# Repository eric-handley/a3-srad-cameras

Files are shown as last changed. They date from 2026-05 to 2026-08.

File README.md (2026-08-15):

# SRAD Cameras -  Operator's Manual

Please read the following document carefully as there are several important notes that could result in data loss or damage if ignored. After the rocket is recovered, please follow [Post-Flight Operations](#post-flight-operations).

Various tools for interacting with the camera boards have been provided in `./tools`. Each of these scripts can be passed `-h` as a flag to see the correct usage. Usage of these scripts is also detailed throughout this file. These scripts + this manual is largely written with the assumption that the user is on a reasonably mainstream Linux distro with common tools available. 

You will need a USB-C cable to pull files off of the camera (although the SD card should be imaged after flight as a precaution before doing this) and a USB<->UART adapter to send/receive camera commands/status.

Please send me a message if uncertain about anything or if issues arise!

## Table of Contents

- [Pre-Flight Checklist](#pre-flight-checklist)
    - [FPC Cable](#fpc-cable)
    - [Arducam Module](#arducam-module)
    - [SD Card](#sd-card)
    - [Operational Test](#operational-test)
    - [Before Launch](#before-launch)
- [Important Warnings & Info](#important-warnings--info)
- [Board Info](#board-info)
    - [Camera Status](#camera-status)
    - [Correct FPC Orientation](#correct-fpc-orientation)
    - [Arducam Ribbon connector](#arducam-ribbon-connector)
- [SD Card Operations](#sd-card-operations)
    - [SD Card Format](#sd-card-format)
- [Recovering Recordings](#recovering-recordings)
    - [Post-Flight Operations](#post-flight-operations)
    - [Pulling Recordings Directly](#pulling-recordings-directly)
- [Inspecting Recording Logs for Issues](#inspecting-recording-logs-for-issues)
    - [Common Errors & Causes](#common-errors--causes)
    - [`CAM2` Errata](#cam2-errata)

## Pre-Flight Checklist

This checklist is per-camera, e.g. each item should be checked on each camera module.

##### FPC Cable

- [ ] FPC is securely connected to both boards, without unneccesary strain, bends, or creases
- [ ] The FPC cable is oriented correctly (see [Correct FPC Orientation](#correct-fpc-orientation))
- [ ] The FPC cable is routed safely, away from power cables and PCBs (see [Important Warnings & Info](#important-warnings--info))
- [ ] If time permits, 3D print a cover for `CAM1` (Recovery Bay camera) to hold FPC away from board. Leave gap for airflow over SoC

##### Arducam Module

- [ ] The small black ribbon connector on the back of the module is in place (see [Arducam Ribbon connector](#arducam-ribbon-connector))
- [ ] The lens is oriented properly and lines up with its viewport (into Recovery/out of fuselage)

##### SD Card

- [ ] The SD card has been cleared using [./tools/wipe-sd-data](./tools/wipe-sd-data) (see [SD Card Operations](#sd-card-operations)) OR it has been verified over SSH using the `df` utility that the `/data` partition retains a significant portion of its capacity (preferably >50%)

##### Operational Test

- [ ] The camera board responds to `START`/`STOP` commands and correctly enters into and reports `STARTING`/`RECORDING`/`STOPPING`/`STOPPED` states based on commands from the Flight Computer/Ground Station
- [ ] After the above, the recording/logs can be pulled from the card properly using [./tools/pull-recording](./tools/pull-recording) (see [Recovering Recordings](#recovering-recordings))
- [ ] No non-benign error messages are reported in the various recording log files (see [Inspecting Recording Logs for Issues](#inspecting-recording-logs-for-issues))
- [ ] The resulting files can be properly combined using [./tools/mux](./tools/mux) and play without issues

##### Before Launch

- [ ] Power and UART lines are securely connected to the camera board and to Modular Power Supply/Flight Computer
- [ ] **IMPORTANT**: Slide switch on the camera board is in the `ON` position (closest to USB-C port)

## Important Warnings & Info

> [!WARNING]
> The SD cards already in the cameras have been correctly formatted as the SoC expects. You CANNOT clear or zero the entire SD card as this will wipe the OS!

> [!NOTE]
> The SD cards do not have a standard partition table as the SoC does not support this. This means that if you plug the SD card into your computer you will not see individual partitions/sizes/filesystem types, and it is not possible to pull files off the SD card this way. This is to be expected and is not an error. 

> [!WARNING]
> Do NOT plug in the USB-C cable while the main camera board is either powered through `JST1` or connected to the Modular Power Supply! Neither device has reverse-voltage protection for this scenario and the outcome of this is unpredictable and potentially damaging.

> [!WARNING]
> ALWAYS ensure that the camera reports a `STOPPED`/`0x0` state before switching it off or disconnecting it from the power supply. Sending `STOP` allows the camera to safely power down the SoC and unmount the SD card. While significant consideration has been given to preventing data loss during power-cut events, we do not want this to happen any more than necessary! The only time power should potentially be cut directly is during a non-nominal flight.

> [!NOTE]
> It is not possible to send commands that cause the camera to shut off in an unsafe way (unless the camera decides that this is necessary, e.g. in the case of SoC responses timing out). Sending `START` or `STOP` commands in any state will always be handled in a way that allows the SoC to unmount the SD card and shut down safely.

> [!CAUTION]
> Ensure the 1x22 FPC cable between the main camera board and the Arducam module is routed as far as possible from power cables and PCBs. The FPC should NEVER be pressed up against either the main camera PCB or the back of the Arducam PCB as this may cause the data sent through it to be corrupted. If this happens during flight, the recording will continue safely, but some non-zero number of frames will likely be lost.

## Board Info

### Camera Status

The status LED between the two JST connectors will blink 3 times on power-up to indicate that the STM32 has started. After this has completed, the LED has three possible states that indicate the overall status of the camera:

1. `STANDBY`: 5 seconds off, then 1 short blink
2. `RECORDING`: ~800 ms off, then ~800 ms on
    - Also present while the camera is `STOPPING`
    - The camera will stop `RECORDING` automatically after 30 minutes and shut down
3. `ERROR`: Rapidly blinking on/off every ~100 ms
    - This state may be temporary as the camera will try to recover automatically
    - If `ERROR` persists for more than a couple seconds, the best course of action is to send `STOP`, wait for `STOPPED`, then start the camera in `IDLE` and inspect the logs for the source of the issue
    - If no logs are produced by an `ERROR` state then the SoC never booted - this is caused by the PMIC on the PCB failing to start and the issue is likely related to voltage instability or unstable/poor ground connection. This is also a good first thing to check if errors occur

While the camera is in a transitional state between `STOPPED`/`STANDBY` and `RECORDING`, it will report either `STARTING` or `STOPPING`. This indicates that the SoC is in the process of booting or shutting down safely.

### Correct FPC Orientation

The correct orientation for the FPC ribbon cable is shown below. The cameras (as shipped) already have this orientation and ideally there is no need to disconnect the cable. However, this image can be referenced if necessary. The easiest way to tell that the cable orientation is correct is that the **blue rectangle on each end of the cable** should face: (a) toward the same side as the camera lens and (b) toward the top of the main board

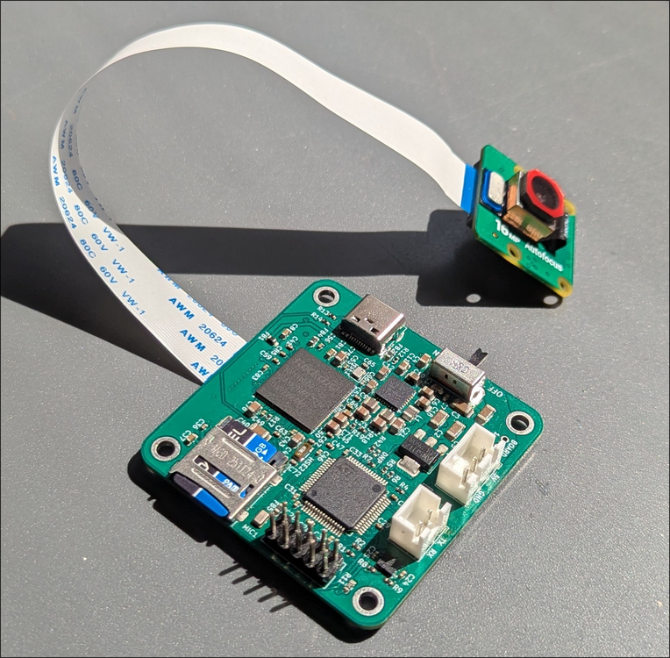
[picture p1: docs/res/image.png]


To disconnect either side of the cable, you must first pull the two black tabs beside the cable out (shown in the image below). If you are pulling on the cable with any amount of force and it is not coming out, you have skipped this step! To put the cable back:

 - Make sure the black tabs are out
 - Insert the cable in the right orientation
 - GENTLY push the black tabs back into place, ideally while holding the other side of the connector 

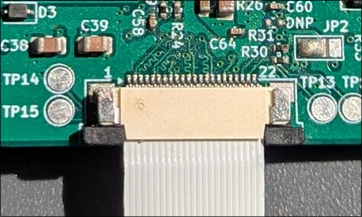
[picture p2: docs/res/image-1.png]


### Arducam Ribbon connector

The back of the Arducam B0371 module has a small ribbon connector that carries various signals/voltages. This cable can easily become disconnected if the module is not handled carefully. Simply align the contacts and push the cable back into place.

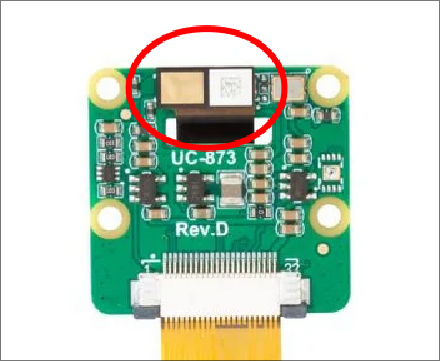
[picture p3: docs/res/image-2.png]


## SD Card Operations

As noted in [Important Warnings & Info](#important-warnings--info), the MicroSD card used by the SoC has a non-standard partition setup to allow the SoC to properly read it. This means that you cannot a) mount the SD card as a regular drive with visible partitions or b) easily pull recordings off of the card by plugging it into your computer. Instead, follow [Recovering Recordings](#recovering-recordings).

### SD Card Format

The majority of the pre-written data on the MicroSD cards is the operating system used by the SoC; this should not be modified or overwritten under any circumstances. All recording data/logs are saved in the `/data` folder, which is a separate partition. All other partitions are always mounted read-only by the OS to avoid corruption. To safely clear the `/data` partition to clear up room for more recordings, you should do the following:

1. Save any recordings you want to keep (see [Pulling Recordings Directly](#pulling-recordings-directly))
2. Plug the SD card into your computer. Ensure it remains unmounted
3. Get the name of the device using `lsblk` (usually `mmcblk0`)
4. Use [./tools/wipe-sd-data](./tools/wipe-sd-data): `./wipe-sd-data <device-name>` to clear the data partition and safely reinitialize the ext4 filesystem it uses. The script will prompt you to confirm that the name of the device is correct before running

It is also possible to free up space by using [./tools/ssh-cam](./tools/ssh-cam) to SSH into a camera board over USB-C, then running `rm -rf /data/*`. However, this has the disadvantage of not fully reinitializing the filesystem used by the `/data` partition (thus potentially leaving corrupted filesystem info behind).

## Recovering Recordings

### Post-Flight Operations

Following recovery of the rocket, the following steps should be taken.

>[!WARNING]
> Do not mount the MicroSD cards and ensure that the computer used for this task will NOT attempt to automatically mount them! Some distros may be configured to do this when new disks are detected. It's unlikely this would cause issues but the risk should not be taken.

1. Switch off each camera and disconnect from Modular Power Supply
2. Remove SD cards from camera boards. Use the [./tools/image-sd](./tools/image-sd) utility to image both SD cards and save the raw contents to a file. Ideally label these `cam1.img` and `cam2.img` accordingly.
    - This is a backup precaution to make sure that (in the event of corruption) we have an exact copy of the disk before the OS attempts to repair it
    - Note: This will take quite a while and requires that your computer have at least 64GiB free
3. Once each camera's SD card has a `.img` file, you can attempt to pull the recordings using the boards directly (see next subsection). This is a significantly easier process than trying to extract them from the `.img` file manually.

### Pulling Recordings Directly

To put the cameras in a state where you can SSH into them or SCP files off of them, you must do the following:

1. Disconnect any other power sources from the board
2. **If post-flight**: Image the SD card as specified in the previous subsection
3. Plug the board into your computer using a USB-C cable
4. Connect a USB<->UART adapter to ground and to the `JST2`/1x2 Flight Computer connector OR the two header pins labled `FC` `RX/TX` on the back of the board.
5. Use [./tools/cam-send](./tools/cam-send) to send an `IDLE` command to the board: `./cam-send idle`. This boots the SoC without starting a recording. 
    - Note that in this mode, the `/data` partition is mounted read-only and therefore direct power cuts are not a concern (but getting in the habit of sending `./cam-send stop` before you disconnect the USB-C is still a good idea)
6. Use [./tools/pull-recording](./tools/pull-recording) to pull a single recording off of the SD card: `./pull-recording latest`
    - If you have not yet registered the camera's USB interface as an ethernet device, the script will prompt you to run `./tools/ssh-cam`, which should handle this automatically
    - `/data/latest` is a symlink to the most recently completed recording
    - Make sure if you are pulling `latest` multiple times that you rename the folder before pulling `latest` again - otherwise the contents will be overwritten.
7. Use [./tools/mux](./tools/mux) to combine the audio/video streams into a single `.mp4` file: `./mux <recording folder name>`
    - Requires `ffmpeg` and `mkvmerge` to be installed
    - Pretty please if you send this somewhere, do it in a way that doesn't destroy the bitrate/compress the video in a way that kills visual quality 🥲

Pulling any recording will also give you a `recordings.log` file. This file lists the folder names of all recordings made, e.g:

```
4aa29dfe5f15 <- saved in /data/4aa29dfe5f15
3362371f0132
7be752e098c8
75d7f5291437
7910d149b82b
becfb81627f5 <- most recent recording folder, /data/latest points here
```

## Inspecting Recording Logs for Issues

The following files should be created/updated by each recording (`START`/`STOP` cycle). If some are missing or duplicated (e.g. the same filename with a `.1`, `.2` suffix - this indicates a supervisor retry), something has gone wrong.

```sh
data
├── latest              # or uuid12 e.g. e051225d1440. `latest` is a symlink for most recent recording
│   ├── audio.log       # logs for `tinycap` which captures audio from ALSA
│   ├── audio.wav       # actual audio output file
│   ├── imu.csv         # timestamped imu data from STM32 along with temperature sensor readings
│   ├── kernel.log      # kernel logs for specific boot that captured this recording
│   ├── supervisor.log  # logs for supervisor script that starts other processes, e.g. video and 
│   │                   # audio recording. also handles logging imu data from STM32
│   ├── vicap.log       # logs from video capture process
│   ├── video.h265      # output h265 video
│   └── video.pts       # timestamps of every frame of h265. allows muxing to time frames 
│                       # correctly instead of distributing evenly according to FPS
├── recordings.log      # records the folder names of each new recording created
└── startup.log         # records an entry each time the supervisor script starts
```

#### Common Errors & Causes

> [!NOTE]
> Expect to see a fair amount of errors like the following:
> ```
>3,309,22874610,-;dwmmc_rockchip ffaa0000.mmc: Card stuck in wrong state! card_busy_detect status: 0x0 caller=mmc_blk_mq_complete_prev_req.part.4+0x89/0xe4
>3,310,22874669,-;MMCDBG mmcblk1: recovery dir=WRITE pos=34940552 cmd_err=0 data_err=0 stop_err=0 status=0xd00 send_status_err=0
>6,311,22889830,-;mmc_host mmc1: Bus speed (slot 0) = 400000Hz (slot req 400000Hz, actual 400000HZ div = 0)
>```
> These are benign and are related to issues with Rockchip's MMC drivers. No data is lost by these, they might just slow down boot times slightly

> ___
> #### Error Message:
>
> None, no new log files were created or most recent recording looks to have exited correctly
>
> #### Behaviour:
> 
> LED goes directly from `STANDBY` state to `ERROR` state and stays there
>
> #### Cause:
>
> Unstable voltage or ground connection. PMIC was never able to start properly so SoC did not boot
> 
> ---

> ___
> #### Error Message:
>
> kernel.log:
> ```
>Unexpected sensor id(xxxx)
>```
>
> #### Behaviour:
> 
> Recording fails to start and no `video.h265` file is present, some log files are missing or supervisor.log reports an error exit value for `uvr-vicap.c`
>
> #### Cause:
>
> Sensor not connected properly; FPC cable either disconnected or oriented wrong. Arducam ribbon cable may be dislodged. 
> 
> ---

> ___
> #### Error Message:
>
> kernel.log:
> ```
> 3,443,486143421,-;mipi-csi2-hw ERR1:0x11000110 (fs/fe mis,vc: 0) (f_seq,vc: 0) (crc,vc: 0) (ecc2) 
> 3,444,486151886,-;mipi-csi2-hw ERR1:0x10000000 (ecc2) 
> 3,447,486168584,-;mipi-csi2-hw ERR2:0x100 (ecc,vc: 0) 
> 3,448,486191410,-;mipi-csi2-hw ERR1:0x10000100 (f_seq,vc: 0) (ecc2) 
> ```
>
> (or similar)
>
> #### Behaviour:
> 
> All log files and output files are present. `vicap.log` may have a large number of `SOF` errors (a small number is normal) or report an FPS different from 60fps at exit
>
> #### Cause:
>
> MIPI errors caused by FPC cable being too close to a PCB or voltage source
> 
> ---

> ___
> #### Error Message:
>
> supervisor.log:
> ```
> [2024-01-01T00:02:19.500143] csv write failed after 11272 rows ([Errno 28] No space left on device), reopening
> ```
>
> #### Behaviour:
> 
> No new recording created; pulled recording looks the same as last one
>
> #### Cause:
>
> `/data` partition is full
> 
> ---

#### `CAM2` Errata

Two things are broken (marginally functional) on `CAM2` (horizon camera) due to questionable soldering:

1. SoC internal temperature sensor
2. Microphone

This means that logs will display `SoC temp nanC` and the audio file will just be noise/*very* faint. `CAM2` may also have kernel logs related to `implausible reading 180C`; these are benign and don't reflect actual temperature readings.

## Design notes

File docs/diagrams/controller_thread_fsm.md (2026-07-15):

```mermaid
---
config:
    flowchart:
        nodeSpacing: 20
        rankSpacing: 150
---
flowchart TD
    Start([Start]) --> IDLE((SYS_IDLE))

    IDLE --> |cached_soc_status == REPLY_ERROR| ERROR((SYS_ERROR))
    IDLE --> |New IMU data| SendIMU[Send to SoC]
    SendIMU --> IDLE
    IDLE --> |FC: GET_STATUS| ReplyStatus[Reply FC: cached_soc_status]:::fcReply
    ReplyStatus --> IDLE
    IDLE --> |FC: START_CAM/STOP_CAM| ForwardCmd[Forward to SoC<br/>Start timeout]
    ForwardCmd --> WAIT((SYS_WAIT))
    IDLE --> |FC: invalid command| ReplyInvalid[Reply FC: INVALID_CMD]:::fcReply
    ReplyInvalid --> IDLE

    WAIT --> |Timeout > 1s| SetError[Set status = REPLY_ERROR]
    SetError --> ERROR
    WAIT --> |New IMU data| SendIMU2[Send to SoC]
    SendIMU2 --> WAIT
    WAIT --> |FC: any command| ReplyBusy[Reply FC: BUSY]:::fcReply
    ReplyBusy --> WAIT
    WAIT --> |SoC: REPLY_ERROR| ERROR
    WAIT --> |SoC: valid status| ReplyFC[Reply FC: cached_soc_status]:::fcReply
    ReplyFC --> IDLE

    ERROR --> |New IMU data| SendIMU3[Discard] --> ERROR
    ERROR --> |FC: any command| ReplyError[Reply FC: ERROR]:::fcReply
    ReplyError --> ERROR

    ERROR --> REC[Attempt recovery] --> |Unsuccessful| ERROR
    REC --> |Successful| IDLE

    classDef fcReply fill:#e1f5ff,stroke:#0066cc,stroke-width:2px
```

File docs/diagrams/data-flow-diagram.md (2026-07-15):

```mermaid
%%{init: {
    'themeVariables': {
        'fontSize': '14px'
    },
    'flowchart': {
      'padding': 10,
      'nodeSpacing': 30,
      'rankSpacing': 60,
      'curve': 'linear'
    }
}}%%

graph
    subgraph CAM["Arducam Camera"]
        SENSOR["IMX519 Sensor"]
        FOCUS["AK7375<br/>Focus Motor"]
    end

    subgraph LAB["Lower Avionics Bay"]
        MPS["Modular Power Supply"]
        FC["Flight Computer"]
    end

    subgraph PCB["Custom PCB"]
        subgraph POW["Power"]
            PMIC
        end

        subgraph Sensors
            IMU["LSM6x IMU"]
        end

        subgraph STOR["Storage"]
            SD["MicroSD<br/>Boot + Storage"]
        end

        subgraph CONTROL["Control + Processing"]
            RC["RV1106<br/>H.265 Encoder"]
            STM["STM32U0<br/>Supervisor + IMU Logger"]
        end

    end

    MPS -->|5V| PMIC
    FC <-->|UART| STM
    SENSOR -->|CSI-2| RC
    RC -->|I2C| FOCUS
    RC -->|I2C| SENSOR

    STM -->|"UART</br>Control/Data"| RC

    RC <-->|SDMMC| SD
    STM <-->|I2C| IMU

    STM -->|I2C| PMIC
```

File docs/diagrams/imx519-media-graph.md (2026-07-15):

```mermaid
flowchart TD
    SENSOR["m00_b_imx519 3-001a\n/dev/v4l-subdev2\nSRGGB10 3072x1728"]
    DPHY["rockchip-csi2-dphy0\n/dev/v4l-subdev1"]
    CSI2["rockchip-mipi-csi2\n/dev/v4l-subdev0"]
    BRIDGE["rkcif-mipi-lvds\n/dev/v4l-subdev5\n(CIF-to-ISP online bridge)"]
    ISP["rkisp-isp-subdev\n/dev/v4l-subdev4"]
    MAIN["rkisp_mainpath\n/dev/video11\nYUYV8_2X8"]
    VENC["VENC\nrkmpp H.265 encoder"]
    MUXER["Muxer / file writer"]
    OUTFILE[("output.h265")]

    LENS["m00_b_ak7375 3-000c\n/dev/v4l-subdev3\n(VCM autofocus lens)"]
    PARAMS["rkisp-input-params\n/dev/video20"]
    STATS["rkisp-statistics\n/dev/video19"]
    RKAIQ["rkaiq 3A engine"]

    SENSOR -->|"pad0 -> pad0"| DPHY
    DPHY -->|"pad1 -> pad0"| CSI2
    CSI2 -->|"internal SoC route"| BRIDGE
    BRIDGE -->|"pad0 -> pad0"| ISP
    ISP -->|"pad2 -> pad0"| MAIN
    MAIN --> VENC --> MUXER --> OUTFILE

    ISP -->|"pad3 -> pad0"| STATS --> RKAIQ
    RKAIQ -->|tuning config| PARAMS -->|"pad0 -> pad1"| ISP
    RKAIQ -.->|I2C AE/AWB| SENSOR
    RKAIQ -.->|I2C AF control| LENS
```

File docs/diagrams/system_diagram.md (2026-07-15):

```mermaid
graph LR
    subgraph External
        IMU[LSM6DSL]
        FC[Flight Computer]
        SOC[Rockchip SoC]
    end

    subgraph STM32
        subgraph TXT [ThreadX Threads]
            T_IMU[imu_reader_thread.c]
            T_CTRL[controller_thread.c]
        end

        subgraph TXMQ [ThreadX Message Queues]
            Q_IMU[imu_data_queue]
        end
    end

    IMU --"receive: IMU data"-->T_IMU
    FC <--"send: status <br/> receive: commands"-->T_CTRL
    SOC <--"send: IMU data, commands <br/> receive: status"-->T_CTRL
    
    T_IMU --"send: IMU data"--> Q_IMU
    Q_IMU --"receive: IMU data"--> T_CTRL

    style T_IMU fill:#fff4e1
    style T_CTRL fill:#fff4e1
    style Q_IMU fill:#e8f5e9
    style IMU fill:#cceeff
    style FC fill:#cceeff
    style SOC fill:#cceeff
```

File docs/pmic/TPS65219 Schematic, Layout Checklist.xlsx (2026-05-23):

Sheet: CoverSheet
Texas Instruments
TPS65219xx Check List for Schematic and Layout
Instructions: Use this document as a supplemental checklist to be used along side the TPS65219xx Datasheet, Technical Reference Manual (TRM) and Application notes of PMIC powering specific Processor/SOCs (if applicable). Check off each line item for design assistance. Note: Column D in the schematic checklist is intended to be used for applications not using specific power rails (DCDCs or LDOs) of the PMIC. When power rails are not used, they must be dissabled on the NVM default configuration. If unused power power rails are not disable by default, the PMIC power up sequence will be aborted.

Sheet: Schematic_ChkList
Pin / pins | Description of Use | Connection |  | Check If Complete
 |  | For Functional Use | If Not Used
Global Supplies and Reference Voltage
VSYS | Supply for the device's analog and digital circuits | Terminate with 2.2uF capacitor to ground. A ceramic ±20% tolerance capacitor is recommended for use. Due to DC deratign of ceramics, 2 x VIN should be used for the ceramic DC rating of the cap. (i.e. for 3.3V output a cap of at least 6.3V must be selected) | N.A. - Must be used | Open
AGND1, AGND2 | Analog ground pins | Connect to the AGND plane or the common GND plane. If AGND is separate from PGND or common GND use a 0 ohm short "star-connection" near the PMU. | N.A. - Must be used | Open
VDD1P8 | 1.8V Internal Reference Voltage | This pin must be bypassed to ground with a 2.2 μF or greater ceramic capacitor. Do not connect a load to this pin. | N.A. - Must be used | Open
Logic and Analog Inputs
nRSTOUT | Reset-Output to SoC | Connect to external rail or SoC Use a pull-up resistor to 3.3V MCU Power. Typ. Resistor value: 1 kohm - 10 kohm | Leave pin floating | Open
nINT | Interrupt Request output; pulled low to indicate a fault condition | Connect to external rail or SoC Use a pull-up resistor to 3.3V MCU Power. Typ. Resistor value: 1 kohm - 10 kohm | Leave pin floating | Open
GPIO | General Purpose Open-Drain Input/Output. Can be configured to sequence an external rail when used as output. Input-functionality is only used in multi-PMIC configuration. | Connect to external rail or SoC Use a pull-up resistor to 3.3V MCU Power. Typ. Resistor value: 1 Kohm - 10 kohm. | Leave pin floating | Open
GPO1 | General Purpose Open-Drain Output. Can be configured to sequence an external rail | Connect to external rail or SoC Use a pull-up resistor to 3.3V MCU Power. Typ. Resistor value: 1 Kohm - 10 kohm. | Leave pin floating | Open
GPO2 | General Purpose Open-Drain Output. Can be configured to sequence an external rail | Connect to external rail or SoC Use a pull-up resistor to 3.3V MCU Power. Typ. Resistor value: 1 Kohm - 10 kohm. | Leave pin floating | Open
VSEL_SD/VSEL_DDR | Multi-function pin; SD-card-IO voltage select or DDR-voltage select | If configured as 'VSEL_SD': connect to SoC. If configured as 'VSEL_DDR': Hard-wired pull-up, pull-down or floating. Sets output voltage of DCDC to 1.35 V, 1.2 V or register based VOUT. Refer to the corresponding device TRM (located under "Technical documentation" at ti.com) for more information about the programmed configuration for this multi function pin. | N.A. - Must be used | Open
MODE/RESET | Multi-function pin; control switching frequency in 'Mode' configuration, or force a Warm or Cold reset from SoC in 'Reset' configuration | Connect to external rail or SoC. Refer to the corresponding device TRM (located under "Technical documentation" at ti.com) for more information about the programmed configuration for this multi function pin. NOTE: If both MODE/RESET and MODE/STBY are configured as 'MODE', MODE/RESET will take priority and MODE/STBY will be ignored. | N.A. - Must be used | Open
MODE/STBY | Multi-function pin; control switching frequency in 'Mode' configuration, or initiate low power mode in 'STBY' configuration | Connect to external rail or SoC. Refer to the corresponding device TRM (located under "Technical documentation" at ti.com) for more information about the programmed configuration for this multi function pin. NOTE: If both MODE/RESET and MODE/STBY are configured as 'MODE', MODE/RESET will take priority and MODE/STBY will be ignored. | N.A. - Must be used | Open
SCLK, SDA | I2C communication lines: Clock and Data | Connect to external rail or SoC. Use a pull-up resistor to 3.3V MCU Power. Typ. Resistor value: 1 kohm - 10 kohm | Connect to VCC | Open
DCDCs
PVIN_B1_1, PVIN_B2, PVIN_B3 | Input power supply for DCDCs | Connect to VIN supply with a 4.7 uF, 20% tolerance, ceramic capacitor to PGNDx for input capacitance. Must be connected to the same source as Vsys. Due to DC deratign of ceramics, 2 x VIN should be used for the ceramic DC rating of the cap. (i.e. for 3.3V output a cap of at least 6.3V must be selected) | Connect to VSYS, CIN cap is not need for that DCDC. Must follow recommendations for all other pins of that particular unused DCDC. | Open
PVIN_B1_2 | 2nd Power input for DCDC1 | Short to PVIN_B1_1 pin | Connect to VSYS | Open
FB_B1, FB_B2, FB_B3 | Feedback inputs of DCDCs | Short to output voltage of DCDC at output capacitors. | Connect to GND | Open
LX_B1_1, LX_B2, LX_B3 | Switch node for DCDCs | Connect LC low pass filter to pin. 0.47 uH is recommended for most applications. Ceramic, 20% tolerance, 1x10uF (MIN) and 1x47 uF cap are typical for low bandwidth configuration. High bandwidth configuration has higher capacitance requirements. Please check the datasheet to confirm appropriate capacitance based on configured bandwidth (HBW or LBW). Due to DC derating of ceramics, 2 x Vout should be used for the ceramic DC rating of the cap. (i.e. for 3.3V output a cap of at least 6.3V must be selected) | Leave pin floating | Open
LX_B1_2 | Second switch node of DCDC1 | Short to LX_B1_1 pin | Leave pin floating | Open
LDOs
PVIN_LDO1, PVIN_LDO2, PVIN_LDO34 | Input power supply for LDOs | Connect to VIN supply with a 2.2 uF, 20% tolerance, ceramic capacitor to GND for input capacitance. Must be connected to the same source as VCC. Due to DC deratign of ceramics, 2 x VIN should be used for the ceramic DC rating of the cap. (i.e. for 3.3V output a cap of at least 6.3V must be selected) | Connect to VSYS, CIN cap is not need for that DCDC. Must follow recommendations for all other pins of that particular unused DCDC. | Open
VLDO1, VLDO2, VLDO3, VLDO4 | Output of LDOs | Connect a 2.2 uF ceramic, 20% tolerance cap from pin to GND. Due to DC deratign of ceramics, 2 x Vout should be used for the ceramic DC rating of the cap. (i.e. for 3.3V output a cap of at least 6.3V must be selected) | Leave pin floating | Open

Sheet: Layout_ChkList
Pin / pins | Description of Use | Layout Recommendation for Use | Priority | Check If Complete
Global Supplies and Reference Voltage
VSYS | Supply for the device's analog and digital circuits | Place the 2.2uF input cap close to the pin. | Med | Open
AGND1, AGND2 | Analog ground pins | Connect to the AGND plane or the common GND plane. Use multiple vias on more than one signal plane. | Med | Open
VDD1P8 | 1.8V Internal Reference Voltage | Please a 2.2 μF capacitor as close as possible to the VDD1P8 pin. | Med | Open
Logic and Analog Inputs
nRSTOUT | Reset-Output to SoC | No requirements | None | Open
nINT | Interrupt Request output; pulled low to indicate a fault condition | No requirements | None | Open
GPIO | Can be configured to sequence an external rail | No requirements | None | Open
GPO1 | Can be configured to sequence an external rail | No requirements | None | Open
GPO2 | Can be configured to sequence an external rail | No requirements | None | Open
VSEL_SD/VSEL_DDR | Multi-function pin; SD-card-IO voltage select or DDR-voltage select | No requirements | None | Open
MODE/RESET | Multi-function pin; control switching frequency in 'Mode' configuration, or force a Warm or Cold reset from SoC in 'Reset' configuration | No requirements | None | Open
MODE/STBY | Multi-function pin; control switching frequency in 'Mode' configuration, or initiate low power mode in 'STBY' configuration | No requirements | None | Open
SCLK, SDA | I2C communication lines: Clock and Data | See section 7.5 of UM10204 User's Manual from www.i2c.org for recommendations. | None | Open
DCDCs
PVIN_B1_1, PVIN_B2, PVIN_B3 | Input power supply for DCDCs | Place CIN cap as close as possible to the PVIN_BX pins. Do not route any sensitive signals between the cap and the device pin as this node will have high frequency switching currents on the rising ad falling edge of the HS FET. Use short and wide traces or planes to connect VSYS to PVIN_BX pins. Add 3-4 vias per amp of current on the GND pads for each DCDC. (Highest Priority) | High | Open
PVIN_B1_2 | 2nd Power input for DCDC1 | Must be tied to PVIN_B1_1 | High | Open
FB_B1, FB_B2, FB_B3 | Feedback inputs of DCDCs | Route as a trace to the output capacitor(s) of DCDC1. Best practice to avoid routing near any noisy signals such as near the switch node or under the inductor | High | Open
LX_B1_1, LX_B2, LX_B3 | Switch node for DCDCs | Place inductor clsoe to the PMIC and use short & wide traces or planes to connect the pin to the inductor. Do not route any sensitive signals near this node | High | Open
LX_B1_2 | Second switch node of DCDC1 | Must be tied to LX_B1_1 | High | Open
LDOs
PVIN_LDO1, PVIN_LDO2, PVIN_LDO34 | Input power supply for LDOs | Use a trace or plane to connect to the VSYS input supply | Med | Open
VLDO1, VLDO2, VLDO3, VLDO4 | Output of LDOs | Place the output cap close to the PMIC. Use short & wide traces or planes to avoid IR drops from the LDO to the load. | Med | Open

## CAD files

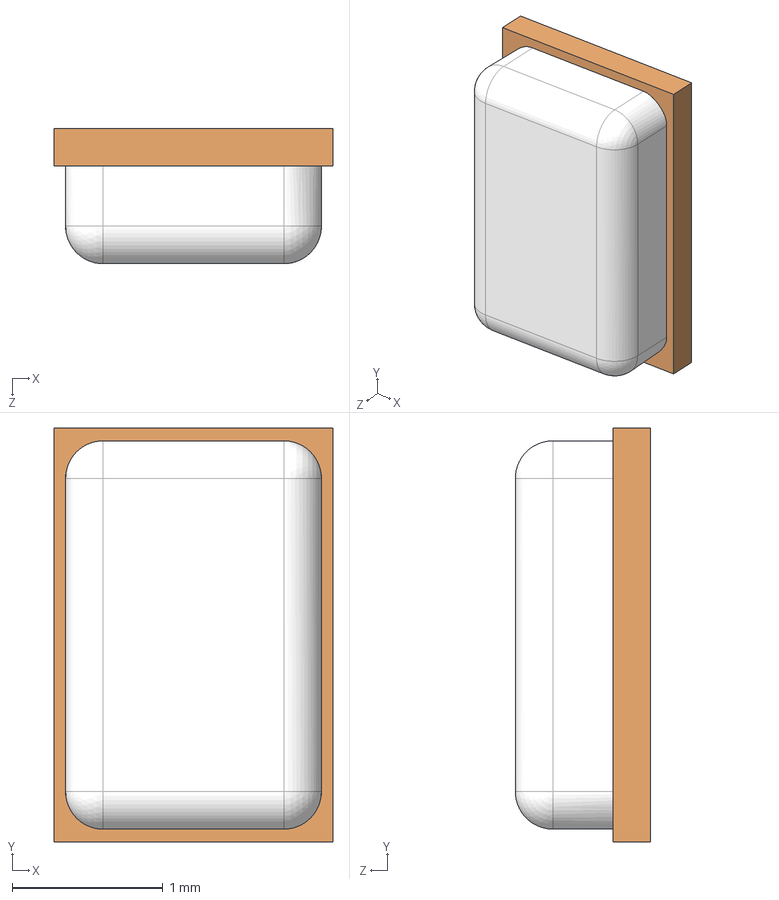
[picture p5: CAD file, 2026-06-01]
kicad/a3-srad-camera-v2.models/CMM-2718AB-3815NC-TR.step
1.85 x 2.75 x 0.9 mm

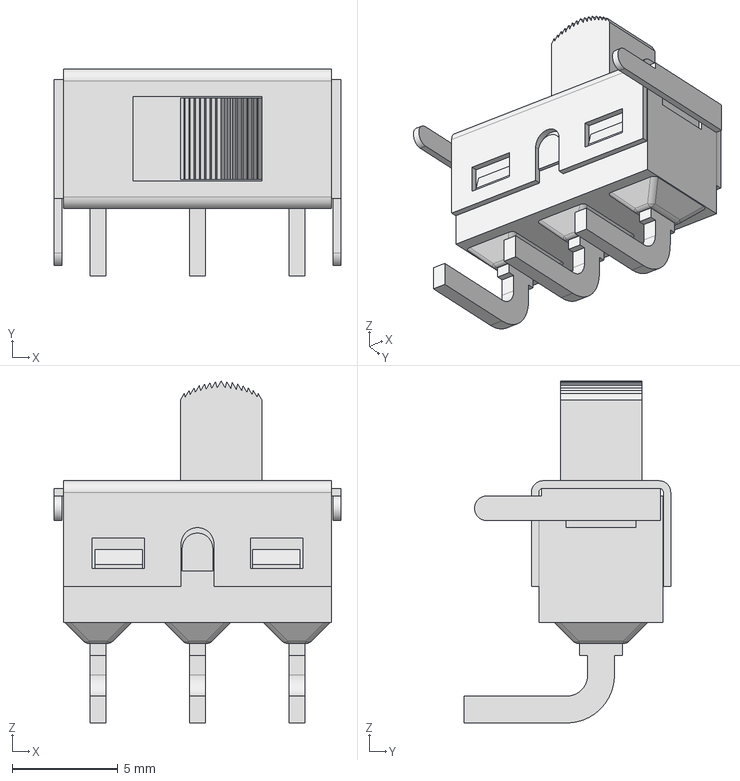
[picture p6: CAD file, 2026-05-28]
kicad/a3-srad-camera-v2.models/500SSP1S1M6QEA.step
13.6 x 9.78 x 16.2 mm

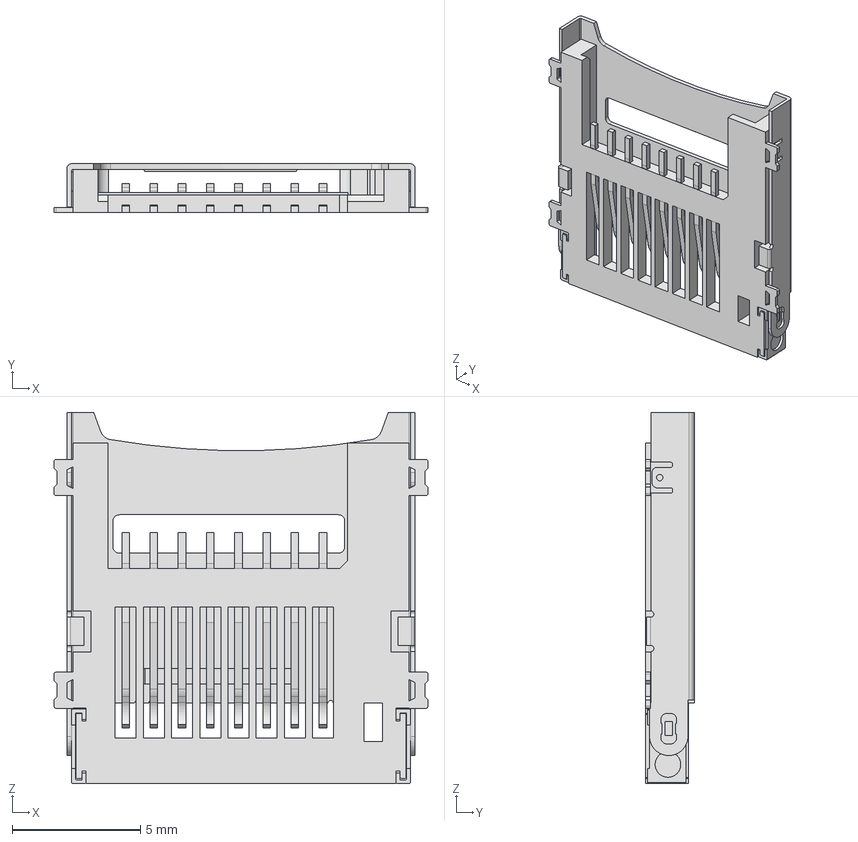
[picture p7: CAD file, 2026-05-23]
kicad/a3-srad-camera-v2.models/MOLEX_0472192001.STEP
14.6 x 1.90 x 14.5 mm

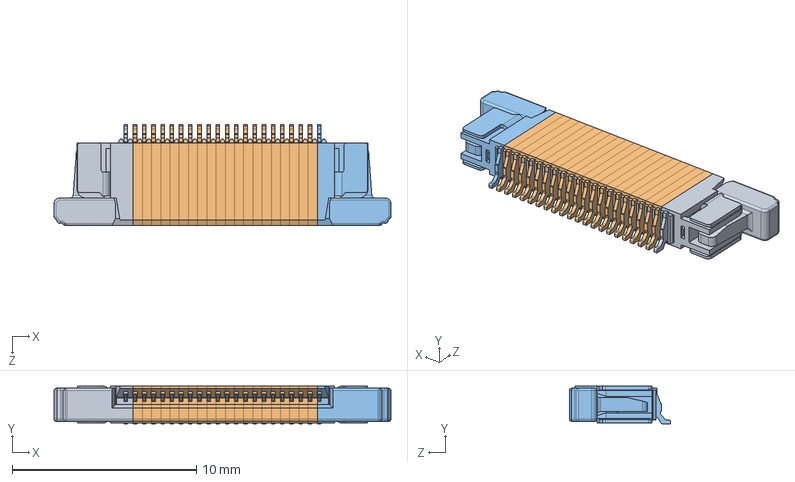
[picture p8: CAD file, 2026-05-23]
kicad/a3-srad-camera-v2.models/F32Q-1A7H1-11022.STEP
18.3 x 2.05 x 5.50 mm
F32Q_L.STEP
F32Q_M.STEP x 20
F32Q_R.STEP

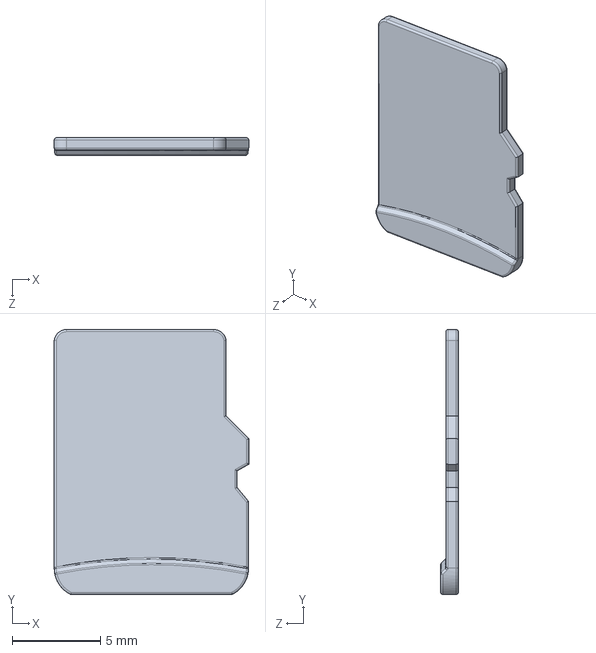
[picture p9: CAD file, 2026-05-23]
kicad/a3-srad-camera-v2.models/Micro SD Card.STEP
11.0 x 15.0 x 1.00 mm

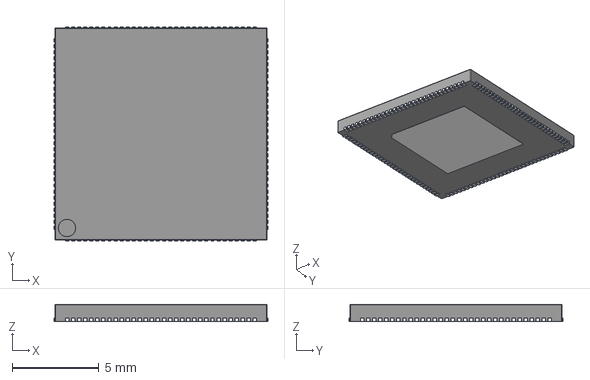
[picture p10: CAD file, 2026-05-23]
kicad/a3-srad-camera-v2.models/QFN-128-1EP_12.3x12.3mm_P0.35mm_EP7x7mm.step
12.4 x 12.4 x 1.00 mm
pins

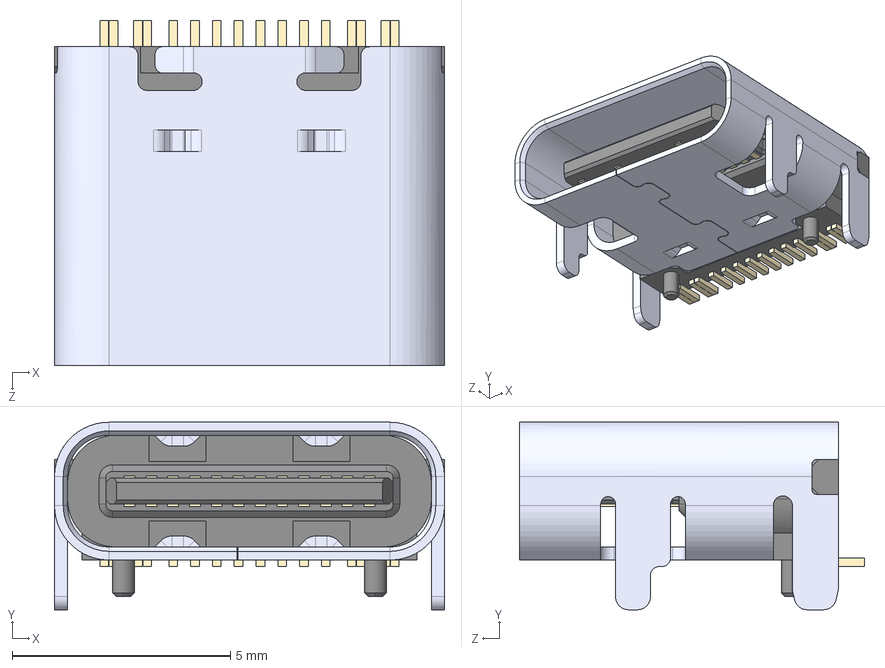
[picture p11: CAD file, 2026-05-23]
kicad/a3-srad-camera-v2.models/TYPE-C-31-M-12--3DModel-STEP-56544.STEP
8.94 x 4.30 x 7.90 mm

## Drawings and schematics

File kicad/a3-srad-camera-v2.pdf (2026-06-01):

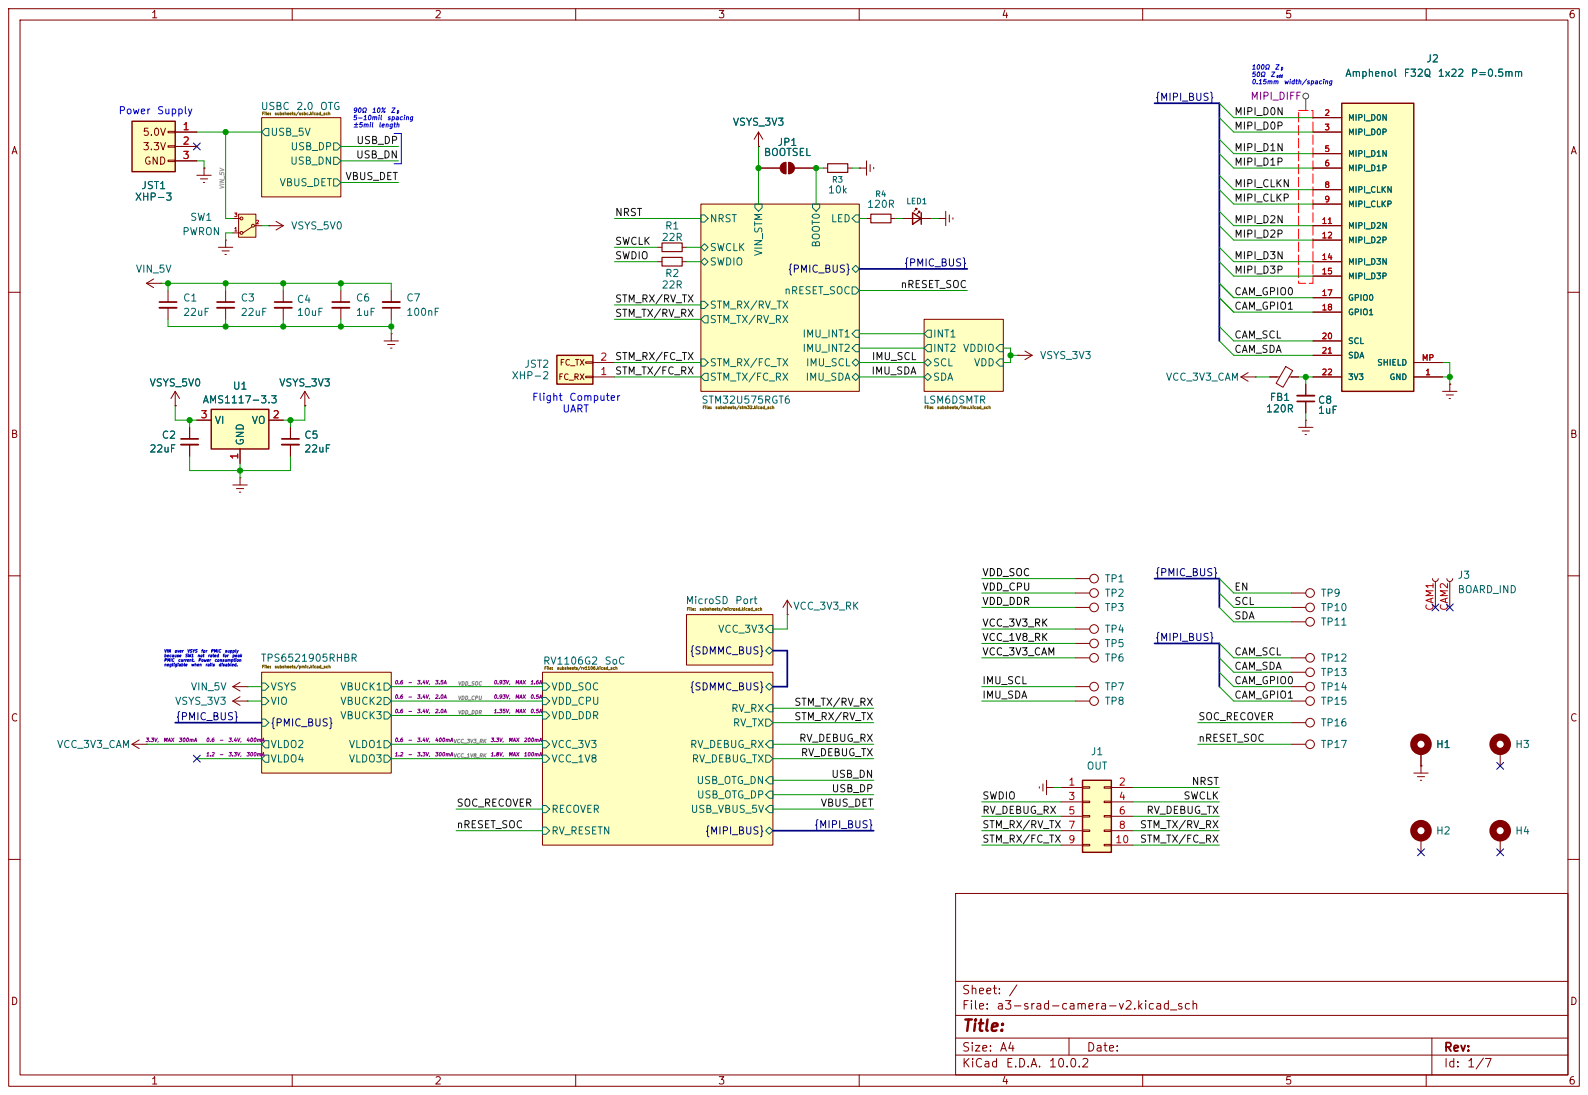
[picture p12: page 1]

VBUS_DET USBC 2.0 OTG File: subsheets/usbc.kicad_sch

LSM6DSMTR File: subsheets/imu.kicad_sch NRST SWCLK VIN_STM

SWDIO
3.3V, MAX 200mA 0.93V, MAX 0.5A 0.93V, MAX 1.6A Flight Computer UART

VIN over VSYS for PMIC supply because SW1 not rated for peak PMIC current. Power consumption negligiable when rails disabled.

Size: A4 | Rev:
KiCad E.D.A. 10.0.2 | Id: 1/7

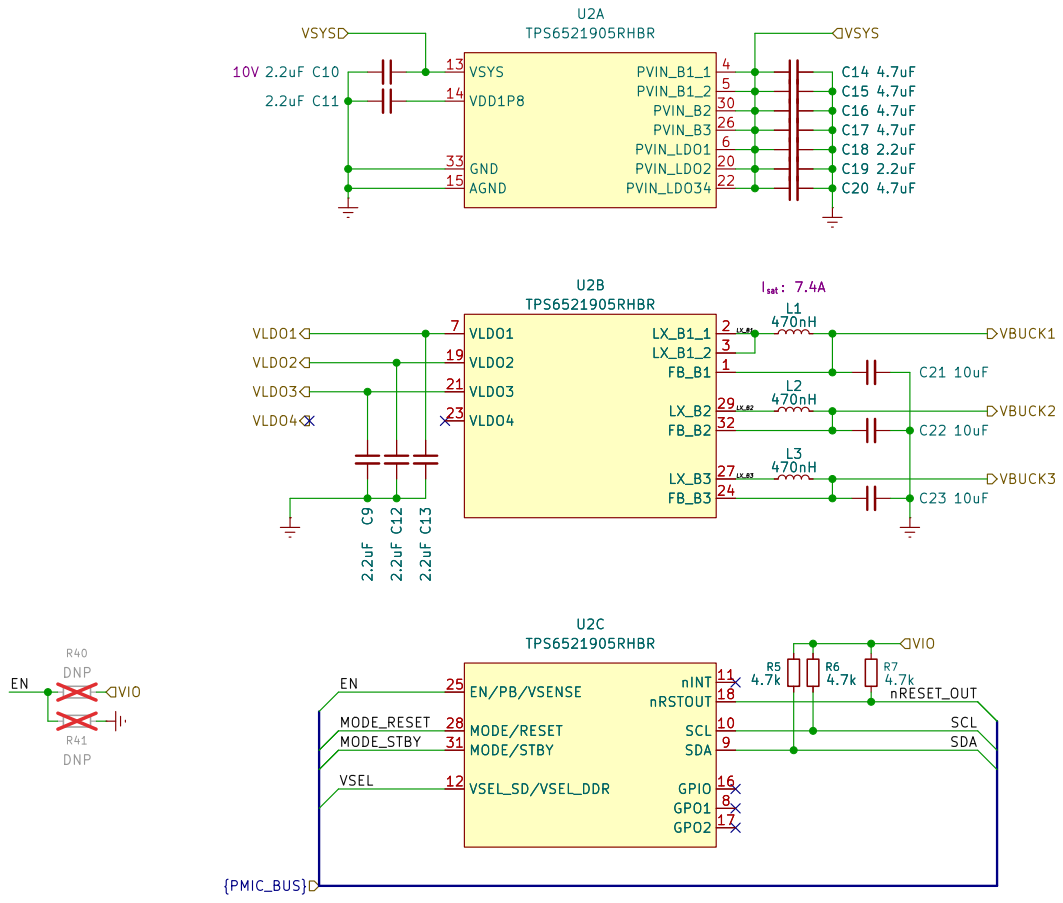
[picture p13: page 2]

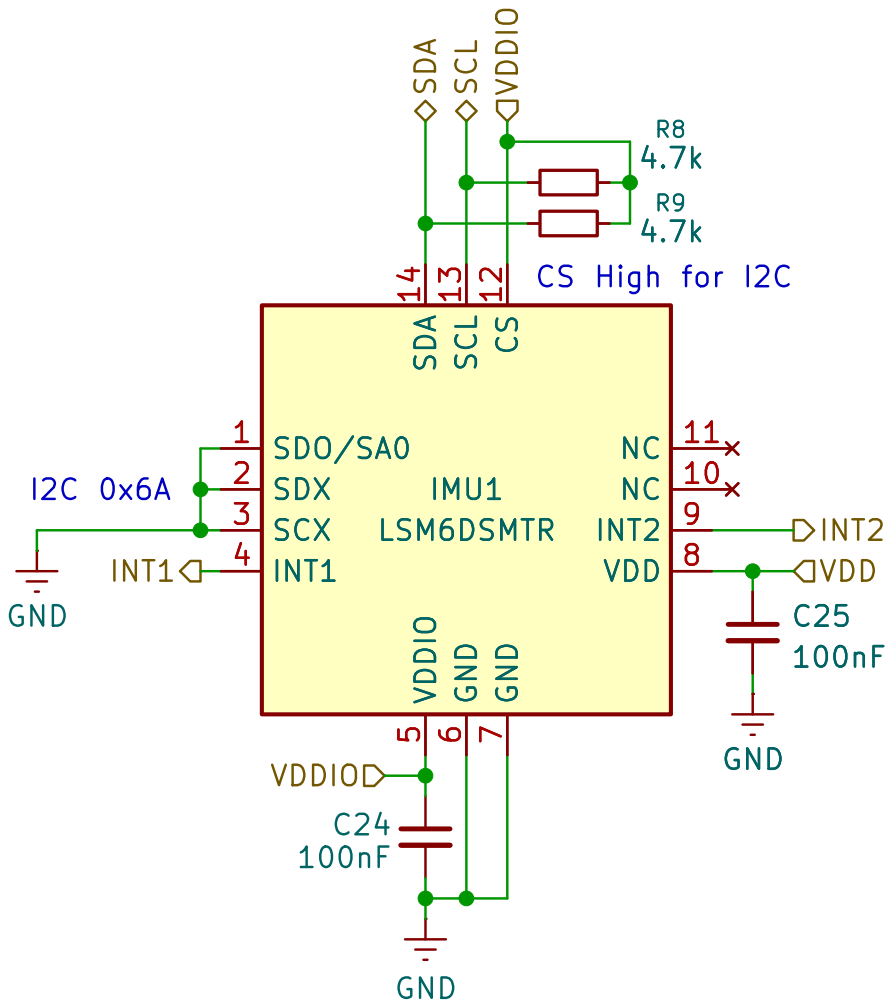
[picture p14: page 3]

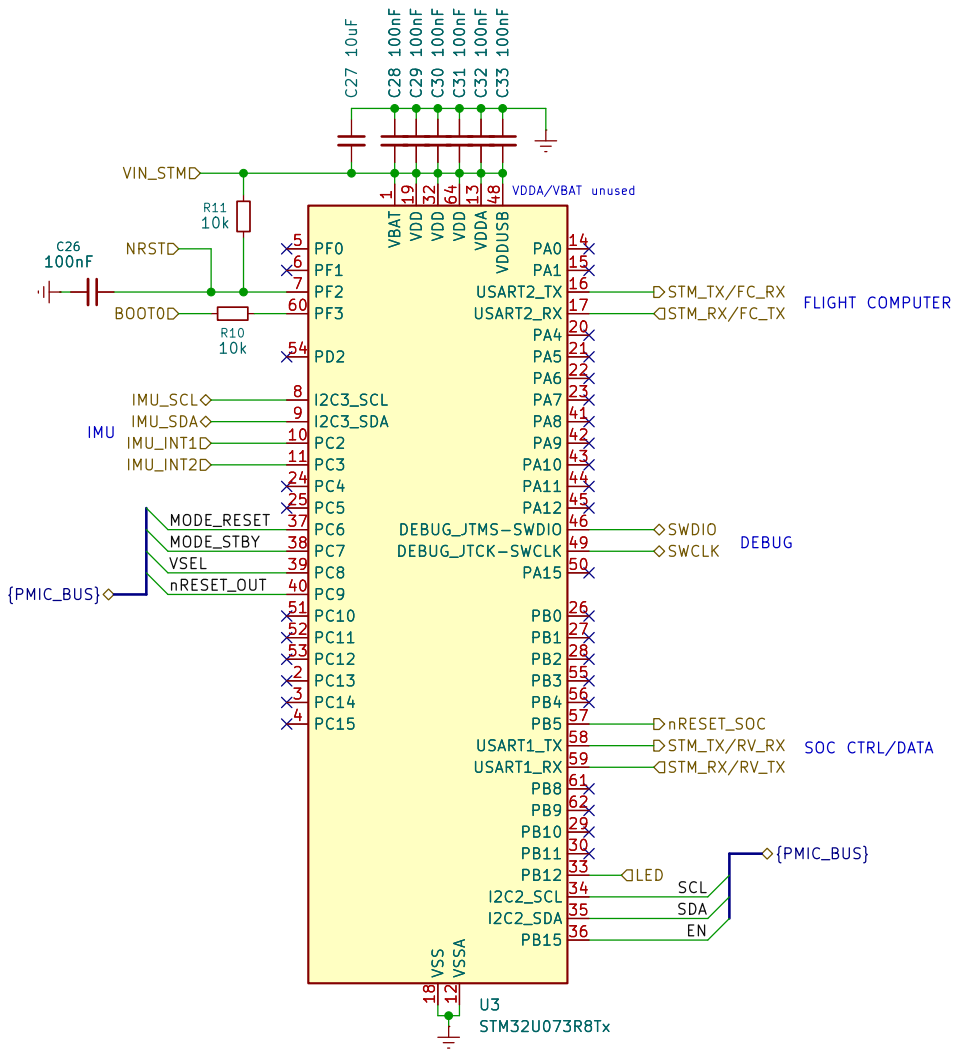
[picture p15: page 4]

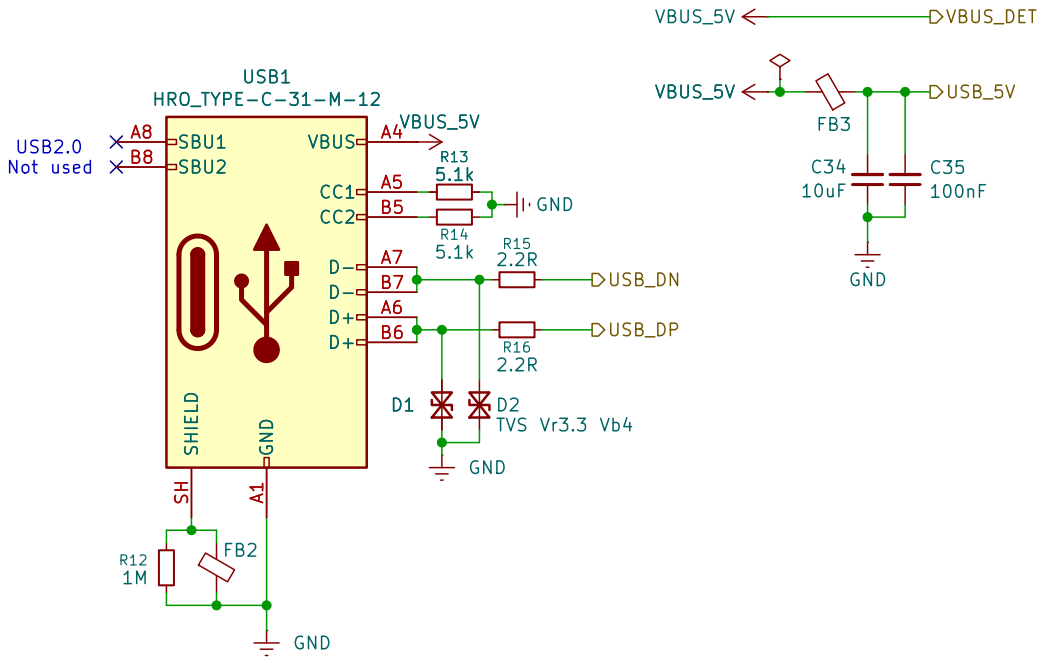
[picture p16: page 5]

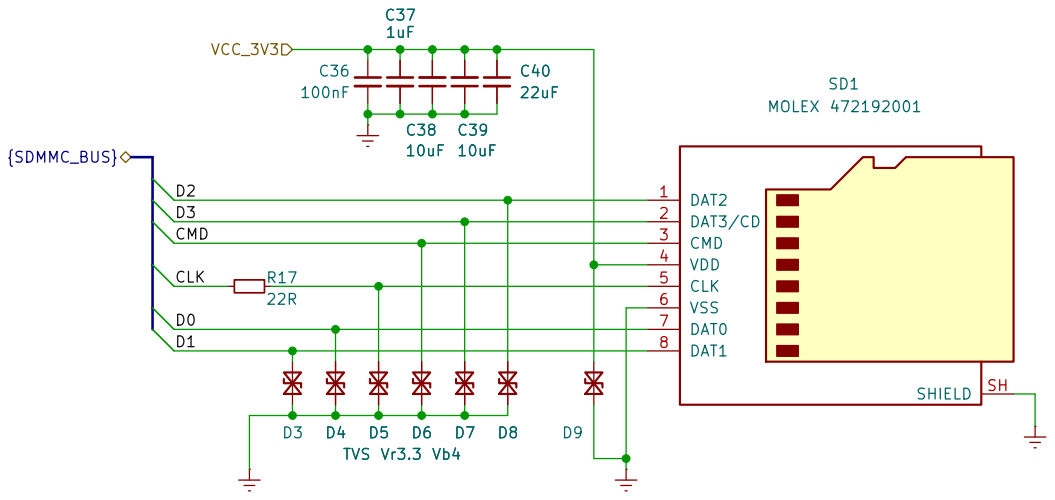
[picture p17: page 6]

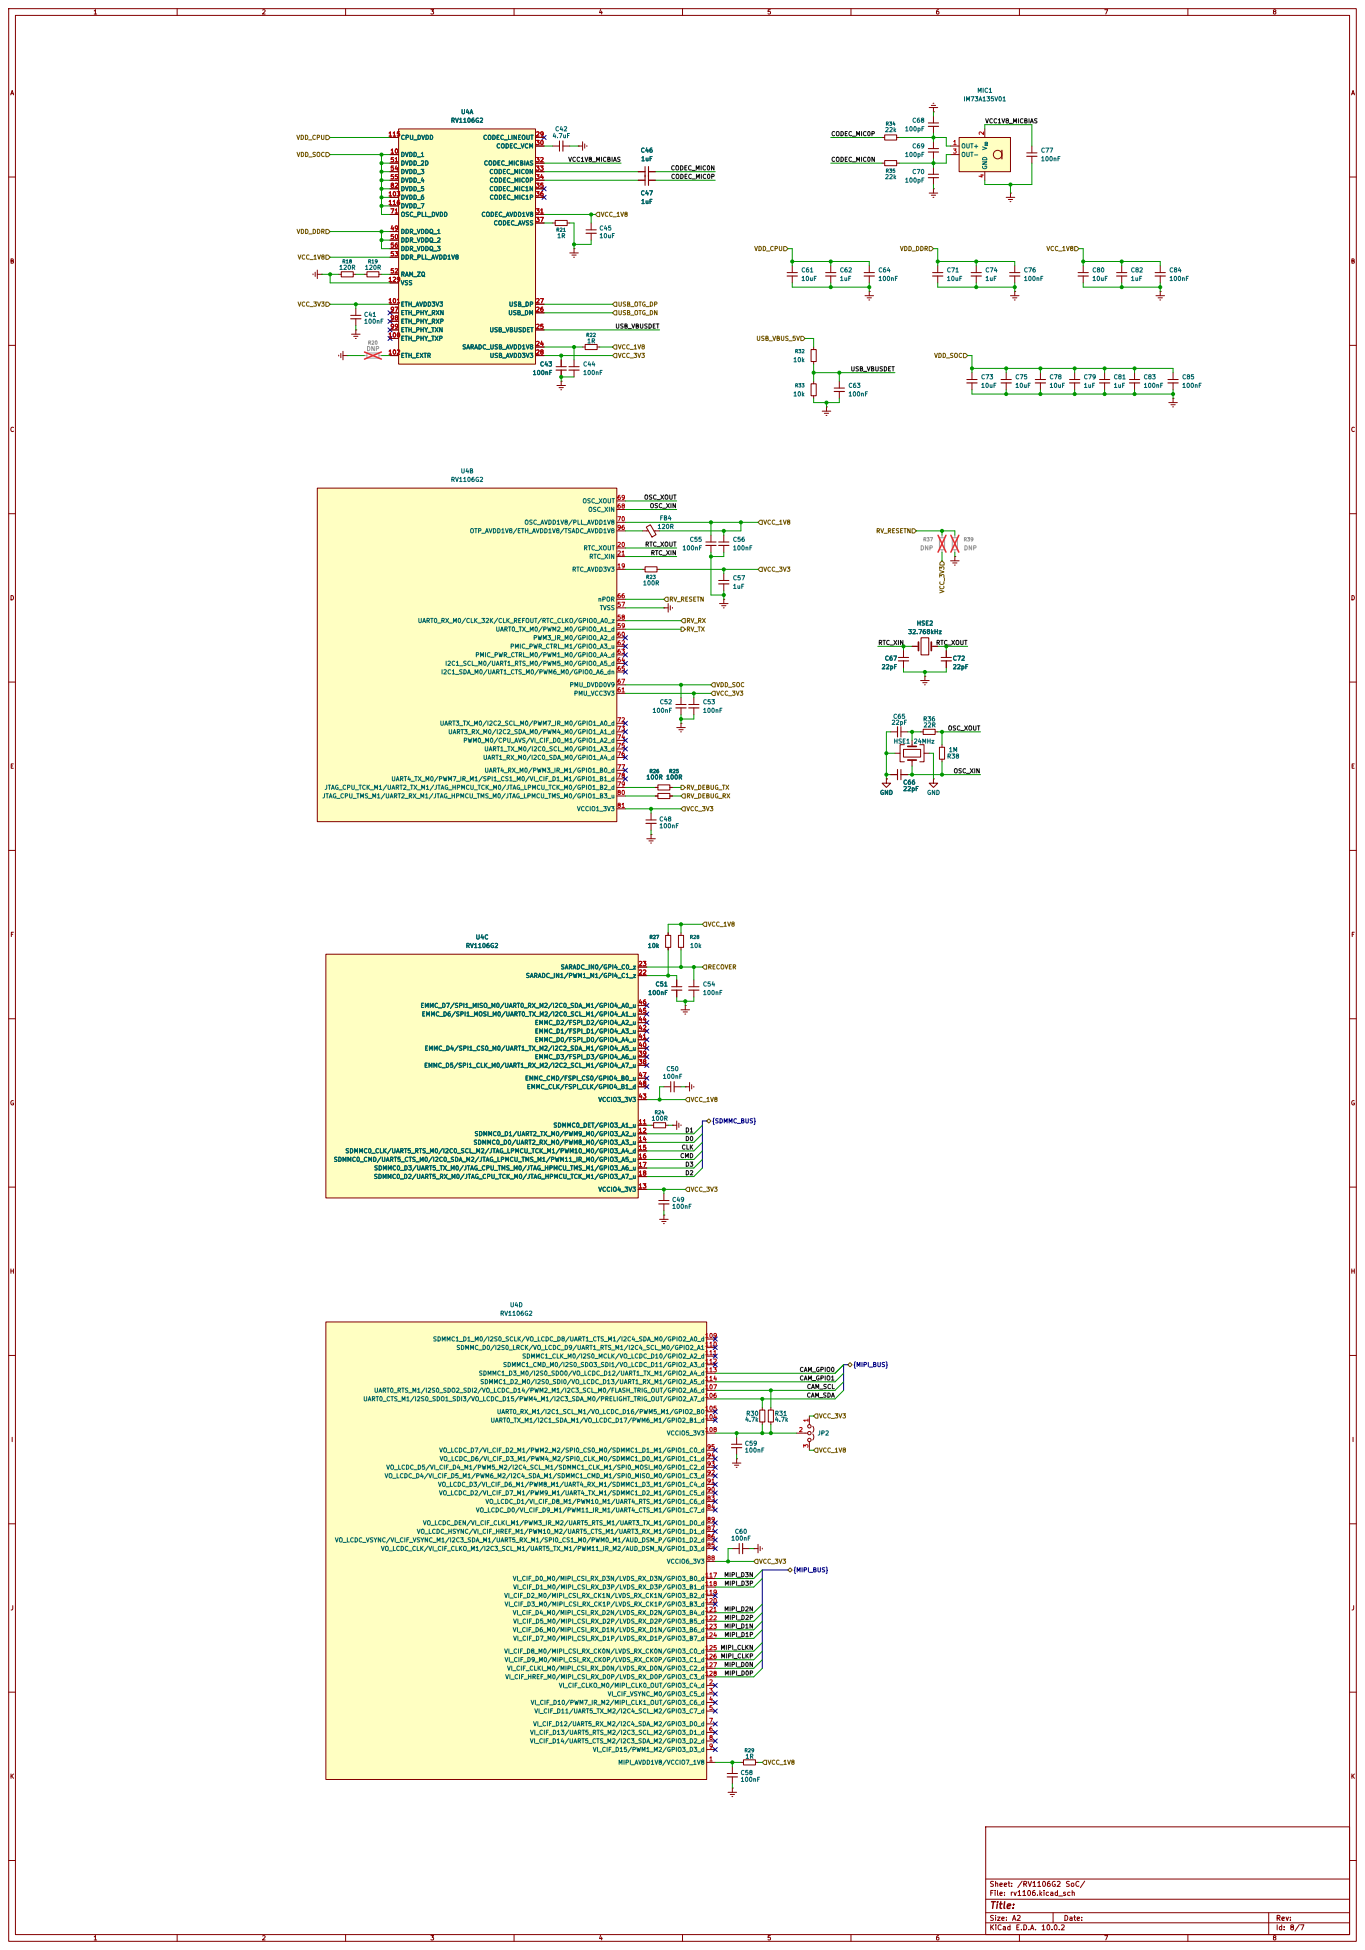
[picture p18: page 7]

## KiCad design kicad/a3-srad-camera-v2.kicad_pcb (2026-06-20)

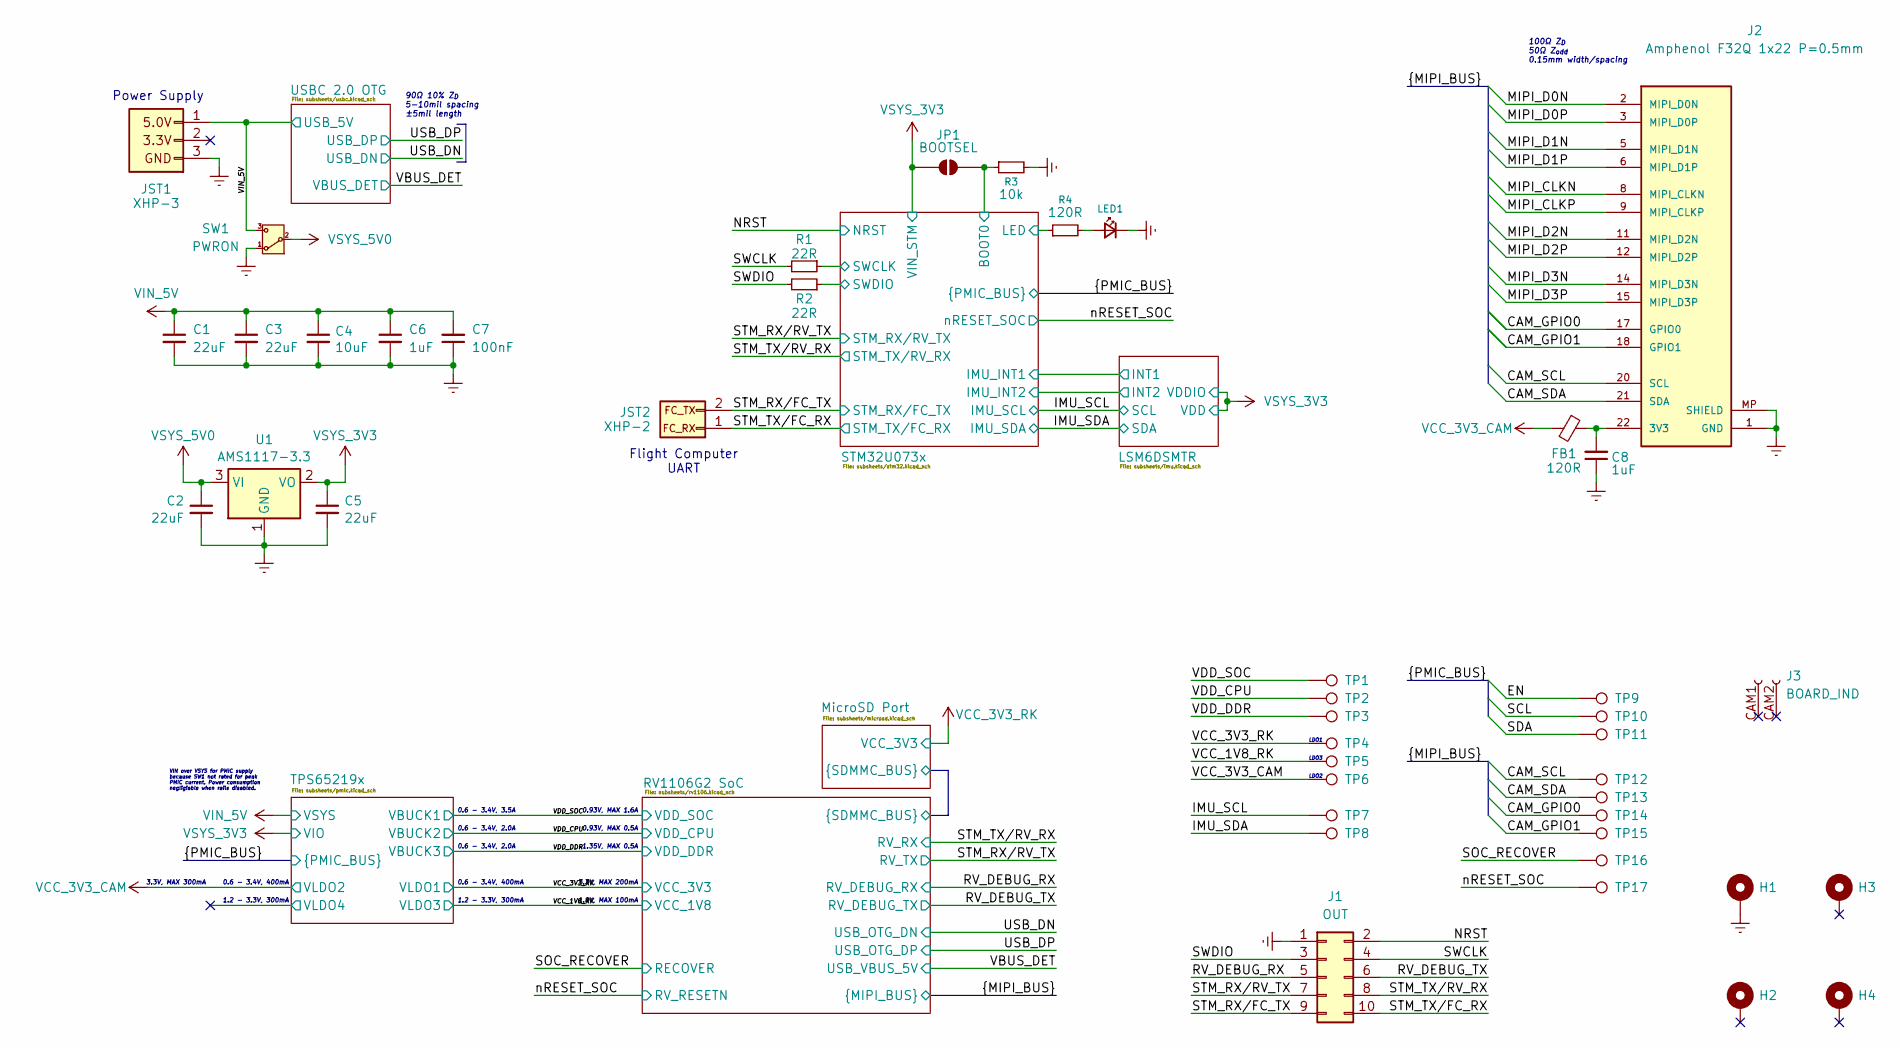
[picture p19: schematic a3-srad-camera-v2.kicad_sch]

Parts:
C1, C3: 22uF; C_1206_3216Metric; LCSC PART NAME C15850
C2, C5: 22uF; C_1206_3216Metric
C4: 10uF; C_0805_2012Metric
C6: 1uF; C_0603_1608Metric
C7: 100nF; C_0402_1005Metric
C8: 1uF; C_0603_1608Metric; LCSC PART NAME C15849
FB1: 120R; R_0603_1608Metric; LCSC PART NAME C14709
H1, H2, H3, H4: MntHole; 4-40_MountingHole
J1: OUT; PinHeader_2x05_P2.54mm_Vertical
J2: Amphenol F32Q 1x22 P=0.5mm; Amphenol_F32Q-1A7x1-11022_1x22-1MP_P0.5mm_Horizontal; PARTREV D
J3: BOARD_IND; Board_Indicator
JP1: BOOTSEL; SolderJumper-2_P1.3mm_Open_Pad1.0x1.5mm
JST1: XHP-3; JST_XH_B3B-XH-A_1x03_P2.50mm_Vertical; LCSC PART NAME C144402
JST2: XHP-2; JST_XH_B2B-XH-A_1x02_P2.50mm_Vertical; LCSC PART NAME C144401
LED1: LED_0805_2012Metric; LCSC PART NAME C2297
R1, R2: 22R; R_0402_1005Metric; LCSC PART NAME C25092
R3: 10k; R_0603_1608Metric; LCSC PART NAME C112291
R4: 120R; R_0402_1005Metric; LCSC PART NAME C112291
SW1: PWRON; SW_Slide_SPDT_Angled_CK_OS102011MA1Q; LCSC PART NAME C221841
TP1, TP2, TP3, TP4, TP5, TP6, TP7, TP8, TP9, TP10, TP11, TP12, TP13, TP14, TP15, TP16, TP17: TestPoint; TestPoint_Pad_D2.0mm_Small_Courtyard
U1: AMS1117-3.3; SOT-223-3_TabPin2

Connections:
/CAM_GPIO0: J2.17 (GPIO0), TP14.1 (1_1); also elsewhere on the board
/CAM_GPIO1: J2.18 (GPIO1), TP15.1 (1_1); also elsewhere on the board
/CAM_SCL: J2.20 (SCL), TP12.1 (1_1); also elsewhere on the board
/CAM_SDA: J2.21 (SDA), TP13.1 (1_1); also elsewhere on the board
/EN: TP9.1 (1_1); also elsewhere on the board
/IMU_SCL: TP7.1 (1_1); also elsewhere on the board
/IMU_SDA: TP8.1 (1_1); also elsewhere on the board
/MIPI_CLKN: J2.8 (MIPI_CLKN); also elsewhere on the board
/MIPI_CLKP: J2.9 (MIPI_CLKP); also elsewhere on the board
/MIPI_D0N: J2.2 (MIPI_D0N); also elsewhere on the board
/MIPI_D0P: J2.3 (MIPI_D0P); also elsewhere on the board
/MIPI_D1N: J2.5 (MIPI_D1N); also elsewhere on the board
/MIPI_D1P: J2.6 (MIPI_D1P); also elsewhere on the board
/MIPI_D2N: J2.11 (MIPI_D2N); also elsewhere on the board
/MIPI_D2P: J2.12 (MIPI_D2P); also elsewhere on the board
/MIPI_D3N: J2.14 (MIPI_D3N); also elsewhere on the board
/MIPI_D3P: J2.15 (MIPI_D3P); also elsewhere on the board
/NRST: J1.2; also elsewhere on the board
/RV_DEBUG_RX: J1.5; also elsewhere on the board
/RV_DEBUG_TX: J1.6; also elsewhere on the board
/SCL: TP10.1 (1_1); also elsewhere on the board
/SDA: TP11.1 (1_1); also elsewhere on the board
/SOC_RECOVER: TP16.1 (1_1); also elsewhere on the board
/STM32U073x/BOOT0: JP1.2 (B), R3.1; also elsewhere on the board
/STM32U073x/LED: R4.1; also elsewhere on the board
/STM32U073x/SWCLK: R1.1; also elsewhere on the board
/STM32U073x/SWDIO: R2.1; also elsewhere on the board
/STM_RX/FC_TX: J1.9, JST2.2; also elsewhere on the board
/STM_RX/RV_TX: J1.7; also elsewhere on the board
/STM_TX/FC_RX: J1.10, JST2.1; also elsewhere on the board
/STM_TX/RV_RX: J1.8; also elsewhere on the board
/SWCLK: J1.4, R1.2
/SWDIO: J1.3, R2.2
/VCC_1V8_RK: TP5.1 (1_1); also elsewhere on the board
/VDD_CPU: TP2.1 (1_1); also elsewhere on the board
/VDD_DDR: TP3.1 (1_1); also elsewhere on the board
/VDD_SOC: TP1.1 (1_1); also elsewhere on the board
/nRESET_SOC: TP17.1 (1_1); also elsewhere on the board
GND: C1.2, C2.2, C3.2, C4.2, C5.2, C6.2, C7.1, C8.1, H1.1 (MP_1), J1.1, J2.1 (GND), J2.4, J2.7, J2.10, J2.13, J2.16, J2.19, J2.MP (SHIELD), JST1.3, LED1.1 (K), R3.2, SW1.1 (A), U1.1 (GND); also elsewhere on the board
unnamed: C8.2, FB1.1, J2.22 (3V3)
unnamed: LED1.2 (A), R4.2
VCC_3V3_CAM: FB1.2, TP6.1 (1_1); also elsewhere on the board
VCC_3V3_RK: TP4.1 (1_1); also elsewhere on the board
VIN_5V: C1.1, C3.1, C4.1, C6.1, C7.2, JST1.1, SW1.3 (C); also elsewhere on the board
VSYS_3V3: C5.1, JP1.1 (A), U1.2 (VO); also elsewhere on the board
VSYS_5V0: C2.1, SW1.2 (B), U1.3 (VI)

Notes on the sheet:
3.3V, MAX 200mA
3.3V, MAX 300mA
VIN over VSYS for PMIC supply because SW1 not rated for peak PMIC current. Power consumption negligiable when rails disabled.
1.8V, MAX 100mA
1.2 - 3.3V, 300mA
0.93V, MAX 0.5A
0.6 - 3.4V, 2.0A
0.6 - 3.4V, 400mA
Power Supply
90Ω 10% Z_{D} 5-10mil spacing ±5mil length
LDO2
LDO1
100Ω Z_{D} 50Ω Z_{odd} 0.15mm width/spacing
0.93V, MAX 1.6A
LDO3
Flight Computer UART
1.35V, MAX 0.5A
0.6 - 3.4V, 3.5A

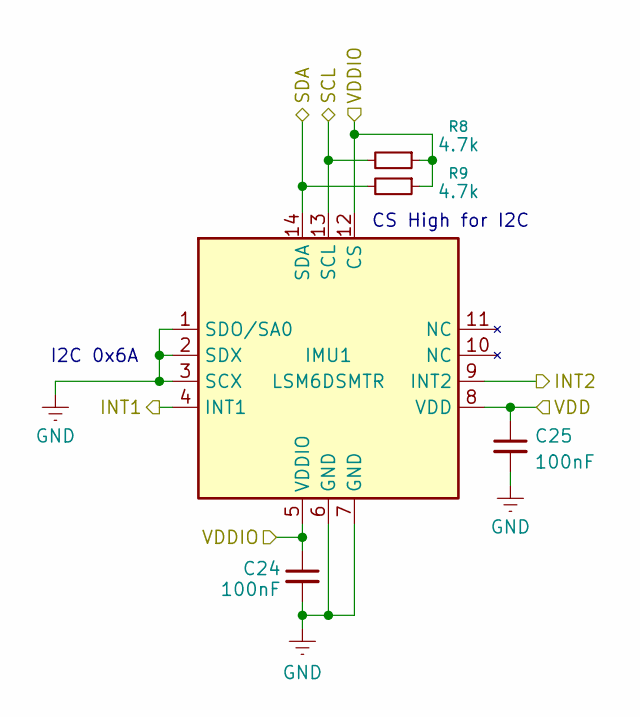
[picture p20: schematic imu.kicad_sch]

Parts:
C24, C25: 100nF; C_0402_1005Metric; LCSC PART NAME C1525
IMU1: LSM6DSMTR; LGA-14_3x2.5mm_P0.5mm_LayoutBorder3x4y; LCSC PART NAME C126672
R8, R9: 4.7k; R_0402_1005Metric; LCSC PART NAME C25900

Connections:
/IMU_SCL: IMU1.13 (SCL), R8.2; also elsewhere on the board
/IMU_SDA: IMU1.14 (SDA), R9.2; also elsewhere on the board
/LSM6DSMTR/INT1: IMU1.4 (INT1); also elsewhere on the board
/LSM6DSMTR/INT2: IMU1.9 (INT2); also elsewhere on the board
GND: C24.2, C25.2, IMU1.1 (SDO/SA0), IMU1.2 (SDX), IMU1.3 (SCX), IMU1.6 (GND), IMU1.7 (GND); also elsewhere on the board
VSYS_3V3: C24.1, C25.1, IMU1.5 (VDDIO), IMU1.8 (VDD), IMU1.12 (CS), R8.1, R9.1; also elsewhere on the board

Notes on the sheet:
I2C 0x6A
CS High for I2C

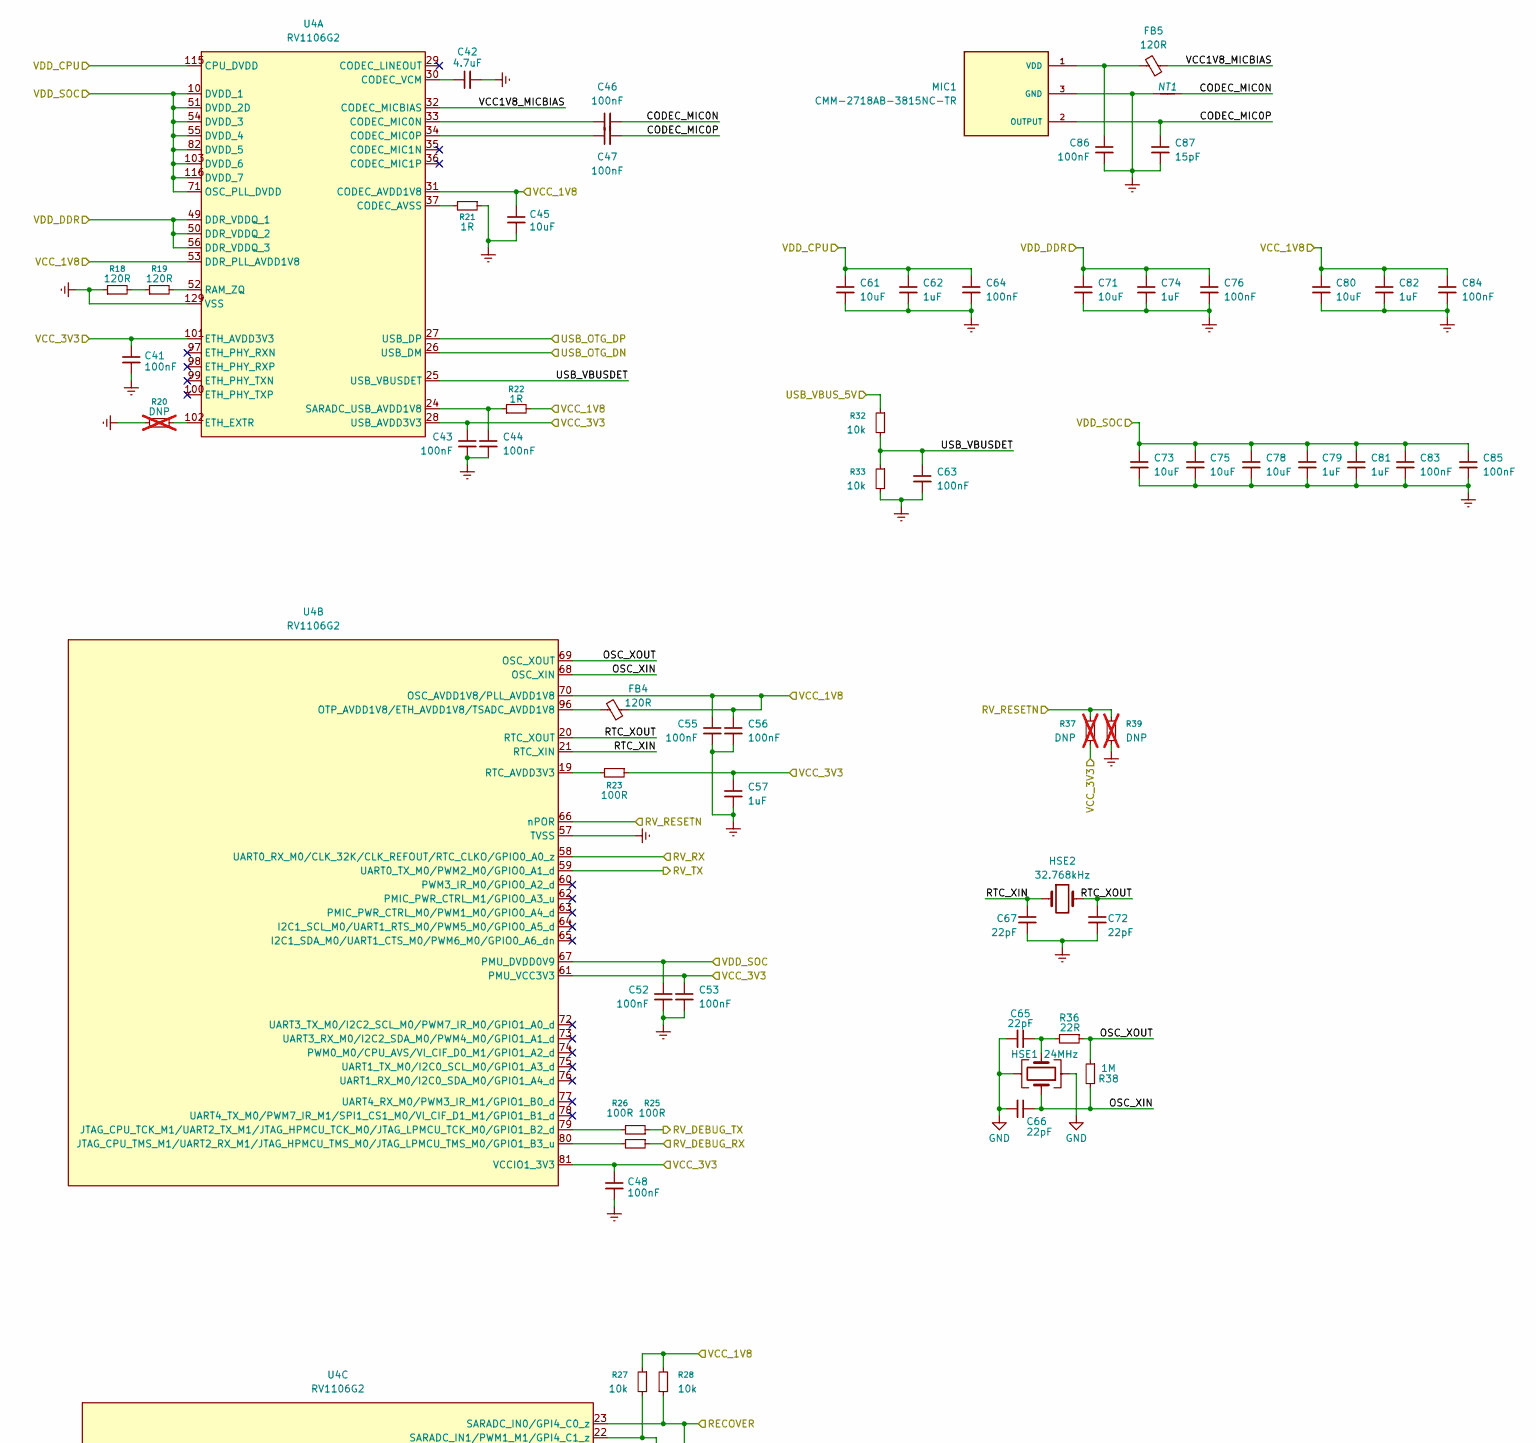
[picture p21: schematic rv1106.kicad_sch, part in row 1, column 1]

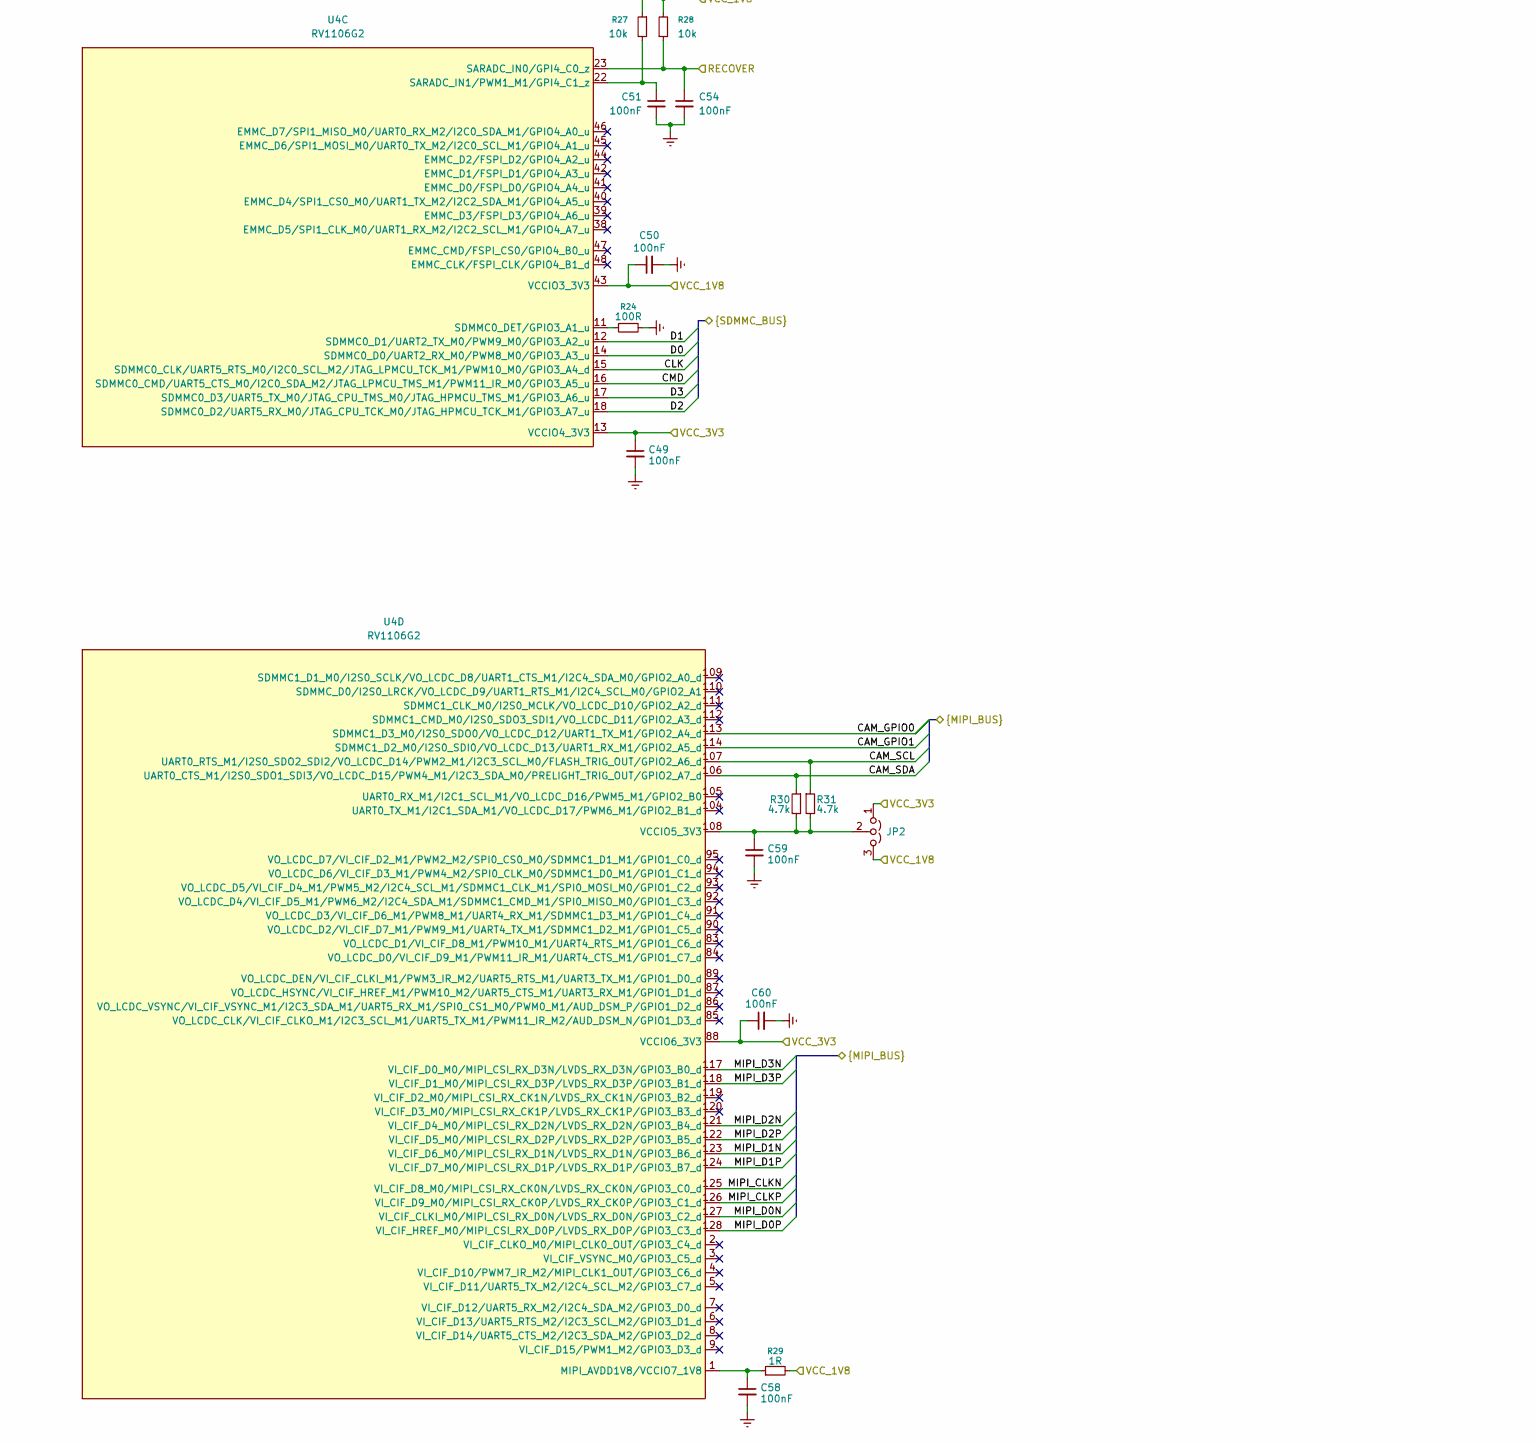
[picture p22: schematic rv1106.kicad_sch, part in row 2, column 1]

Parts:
C41, C43, C44, C46, C47, C48, C49, C50, C51, C52, C53, C54, C55, C56, C58, C59, C60, C63, C64, C76, C83, C84, C85, C86: 100nF; C_0402_1005Metric
C42: 4.7uF; C_0805_2012Metric
C45, C61, C71, C73, C75, C78, C80: 10uF; C_0805_2012Metric
C57, C62, C74, C79, C81, C82: 1uF; C_0603_1608Metric
C65, C66, C67, C72: 22pF; C_0402_1005Metric; LCSC PART NAME C1555
C87: 15pF; C_0402_1005Metric
FB4, FB5: 120R; R_0603_1608Metric
HSE1: 24MHz; Crystal_SMD_2016-4Pin_2.0x1.6mm; LCSC PART NAME C725986
HSE2: 32.768kHz; Crystal_SMD_3215-2Pin_3.2x1.5mm; LCSC PART NAME C32346
JP2: Jumper_3_Open; SolderJumper-3_P1.3mm_Open_Pad1.0x1.5mm_NumberLabels
MIC1: CMM-2718AB-3815NC-TR; MIC_CMM-2718AB-3815NC-TR; PARTREV 1.02
NT1: NetTie_2
R18, R19: 120R; R_0402_1005Metric
R20, R37, R39: DNP; R_0402_1005Metric; not fitted
R21, R22, R29: 1R; R_0402_1005Metric
R23, R24, R25, R26: 100R; R_0402_1005Metric
R27, R28, R32, R33: 10k; R_0603_1608Metric; LCSC PART NAME C112291
R30, R31: 4.7k; R_0402_1005Metric; LCSC PART NAME C25092
R36: 22R; R_0402_1005Metric; LCSC PART NAME C25092
R38: 1M; R_0402_1005Metric; LCSC PART NAME C26083
U4: RV1106G2; QFN-128_L12.3-W12.3-P0.35-TL-EP7.0-1; MPN RV1106G2; LCSC Part C5272606

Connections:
/CAM_GPIO0: U4.113 (SDMMC1_D3_M0/I2S0_SDO0/VO_LCDC_D12/UART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); also elsewhere on the board
/CAM_GPIO1: U4.114 (SDMMC1_D2_M0/I2S0_SDI0/VO_LCDC_D13/UART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); also elsewhere on the board
/CAM_SCL: R31.1, U4.107 (UART0_RTS_M1/I2S0_SDO2_SDI2/VO_LCDC_D14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); also elsewhere on the board
/CAM_SDA: R30.1, U4.106 (UART0_CTS_M1/I2S0_SDO1_SDI3/VO_LCDC_D15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); also elsewhere on the board
/MIPI_CLKN: U4.125 (VI_CIF_D8_M0/MIPI_CSI_RX_CK0N/LVDS_RX_C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); also elsewhere on the board
/MIPI_CLKP: U4.126 (VI_CIF_D9_M0/MIPI_CSI_RX_CK0P/LVDS_RX_C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); also elsewhere on the board
/MIPI_D0N: U4.127 (VI_CIF_CLKI_M0/MIPI_CSI_RX_D0N/LVDS_RX_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); also elsewhere on the board
/MIPI_D0P: U4.128 (VI_CIF_HREF_M0/MIPI_CSI_RX_D0P/LVDS_RX_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); also elsewhere on the board
/MIPI_D1N: U4.123 (VI_CIF_D6_M0/MIPI_CSI_RX_D1N/LVDS_RX_D1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); also elsewhere on the board
/MIPI_D1P: U4.124 (VI_CIF_D7_M0/MIPI_CSI_RX_D1P/LVDS_RX_D1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); also elsewhere on the board
/MIPI_D2N: U4.121 (VI_CIF_D4_M0/MIPI_CSI_RX_D2N/LVDS_RX_D2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); also elsewhere on the board
/MIPI_D2P: U4.122 (VI_CIF_D5_M0/MIPI_CSI_RX_D2P/LVDS_RX_D2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); also elsewhere on the board
/MIPI_D3N: U4.117 (VI_CIF_D0_M0/MIPI_CSI_RX_D3N/LVDS_RX_D3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); also elsewhere on the board
/MIPI_D3P: U4.118 (VI_CIF_D1_M0/MIPI_CSI_RX_D3P/LVDS_RX_D3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); also elsewhere on the board
/MicroSD Port/CLK: U4.15 (SDMMC0_CLK/UART5_RTS_M0/I2C0_SCL_M2/JTA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); also elsewhere on the board
/MicroSD Port/CMD: U4.16 (SDMMC0_CMD/UART5_CTS_M0/I2C0_SDA_M2/JTA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); also elsewhere on the board
/MicroSD Port/D0: U4.14 (SDMMC0_D0/UART2_RX_M0/PWM8_M0/GPIO3_A3_u); also elsewhere on the board
/MicroSD Port/D1: U4.12 (SDMMC0_D1/UART2_TX_M0/PWM9_M0/GPIO3_A2_u); also elsewhere on the board
/MicroSD Port/D2: U4.18 (SDMMC0_D2/UART5_RX_M0/JTAG_CPU_TCK_M0/J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); also elsewhere on the board
/MicroSD Port/D3: U4.17 (SDMMC0_D3/UART5_TX_M0/JTAG_CPU_TMS_M0/J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); also elsewhere on the board
/RV1106G2 SoC/CODEC_MIC0N: C46.2, NT1.2
/RV1106G2 SoC/CODEC_MIC0P: C47.2, C87.1, MIC1.2 (OUTPUT)
/RV1106G2 SoC/OSC_XIN: C66.1, HSE1.1, R38.2, U4.68 (OSC_XIN)
/RV1106G2 SoC/OSC_XOUT: R36.1, R38.1, U4.69 (OSC_XOUT)
/RV1106G2 SoC/RTC_XIN: C67.1, HSE2.1, U4.21 (RTC_XIN)
/RV1106G2 SoC/RTC_XOUT: C72.1, HSE2.2, U4.20 (RTC_XOUT)
/RV1106G2 SoC/USB_VBUSDET: C63.1, R32.2, R33.1, U4.25 (USB_VBUSDET)
/RV1106G2 SoC/VCC1V8_MICBIAS: FB5.1, U4.32 (CODEC_MICBIAS)
/RV_DEBUG_RX: R26.1; also elsewhere on the board
/RV_DEBUG_TX: R25.1; also elsewhere on the board
/SOC_RECOVER: C54.1, R28.1, U4.23 (SARADC_IN0/GPI4_C0_z); also elsewhere on the board
/STM_RX/RV_TX: U4.59 (UART0_TX_M0/PWM2_M0/GPIO0_A1_d); also elsewhere on the board
/STM_TX/RV_RX: U4.58 (UART0_RX_M0/CLK_32K/CLK_REFOUT/RTC_CLKO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); also elsewhere on the board
/USB_DN: U4.26 (USB_DM); also elsewhere on the board
/USB_DP: U4.27 (USB_DP); also elsewhere on the board
/VCC_1V8_RK: C45.1, C50.1, C55.1, C56.1, C80.1, C82.1, C84.1, FB4.1, JP2.3 (B), R22.2, R27.1, R28.2, R29.2, U4.31 (CODEC_AVDD1V8), U4.43 (VCCIO3_3V3), U4.53 (DDR_PLL_AVDD1V8), U4.70 (OSC_AVDD1V8/PLL_AVDD1V8); also elsewhere on the board
/VDD_CPU: C61.1, C62.1, C64.1, U4.115 (CPU_DVDD); also elsewhere on the board
/VDD_DDR: C71.1, C74.1, C76.1, U4.49 (DDR_VDDQ_1), U4.50 (DDR_VDDQ_2), U4.56 (DDR_VDDQ_3); also elsewhere on the board
/VDD_SOC: C52.1, C73.1, C75.1, C78.1, C79.1, C81.1, C83.1, C85.1, U4.10 (DVDD_1), U4.51 (DVDD_2D), U4.54 (DVDD_3), U4.55 (DVDD_4), U4.67 (PMU_DVDD0V9), U4.71 (OSC_PLL_DVDD), U4.82 (DVDD_5), U4.103 (DVDD_6), U4.116 (DVDD_7); also elsewhere on the board
/nRESET_SOC: R37.2, R39.2, U4.66 (nPOR); also elsewhere on the board
GND: C41.2, C42.2, C43.2, C44.2, C45.2, C48.2, C49.2, C50.2, C51.2, C52.2, C53.2, C54.2, C55.2, C56.2, C57.2, C58.2, C59.2, C60.2, C61.2, C62.2, C63.2, C64.2, C65.2, C66.2, C67.2, C71.2, C72.2, C73.2, C74.2, C75.2, C76.2, C78.2, C79.2, C80.2, C81.2, C82.2, C83.2, C84.2, C85.2, C86.2, C87.2, HSE1.2, HSE1.4, MIC1.3 (GND), NT1.1, R18.1, R20.1, R21.1, R24.2, R33.2, R39.1, U4.57 (TVSS), U4.129 (VSS); also elsewhere on the board
unnamed: C65.1, HSE1.3, R36.2
unnamed: C59.1, JP2.2 (C), R30.2, R31.2, U4.108 (VCCIO5_3V3)
unnamed: C86.1, FB5.2, MIC1.1 (VDD)
unnamed: R18.2, R19.1
unnamed: R21.2, U4.37 (CODEC_AVSS)
unnamed: C46.1, U4.33 (CODEC_MIC0N)
unnamed: C47.1, U4.34 (CODEC_MIC0P)
unnamed: C42.1, U4.30 (CODEC_VCM)
unnamed: R20.2, U4.102 (ETH_EXTR)
unnamed: R19.2, U4.52 (RAM_ZQ)
unnamed: C44.1, R22.1, U4.24 (SARADC_USB_AVDD1V8)
unnamed: R25.2, U4.79 (JTAG_CPU_TCK_M1/UART2_TX_M1/JTAG_HPMCU_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)
unnamed: R26.2, U4.80 (JTAG_CPU_TMS_M1/UART2_RX_M1/JTAG_HPMCU_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)
unnamed: FB4.2, U4.96 (OTP_AVDD1V8/ETH_AVDD1V8/TSADC_AVDD1V8)
unnamed: R23.2, U4.19 (RTC_AVDD3V3)
unnamed: C51.1, R27.2, U4.22 (SARADC_IN1/PWM1_M1/GPI4_C1_z)
unnamed: R24.1, U4.11 (SDMMC0_DET/GPIO3_A1_u)
unnamed: C58.1, R29.1, U4.1 (MIPI_AVDD1V8/VCCIO7_1V8)
VBUS_5V: R32.1; also elsewhere on the board
VCC_3V3_RK: C41.1, C43.1, C48.1, C49.1, C53.1, C57.1, C60.1, JP2.1 (A), R23.1, R37.1, U4.13 (VCCIO4_3V3), U4.28 (USB_AVDD3V3), U4.61 (PMU_VCC3V3), U4.81 (VCCIO1_3V3), U4.88 (VCCIO6_3V3), U4.101 (ETH_AVDD3V3); also elsewhere on the board

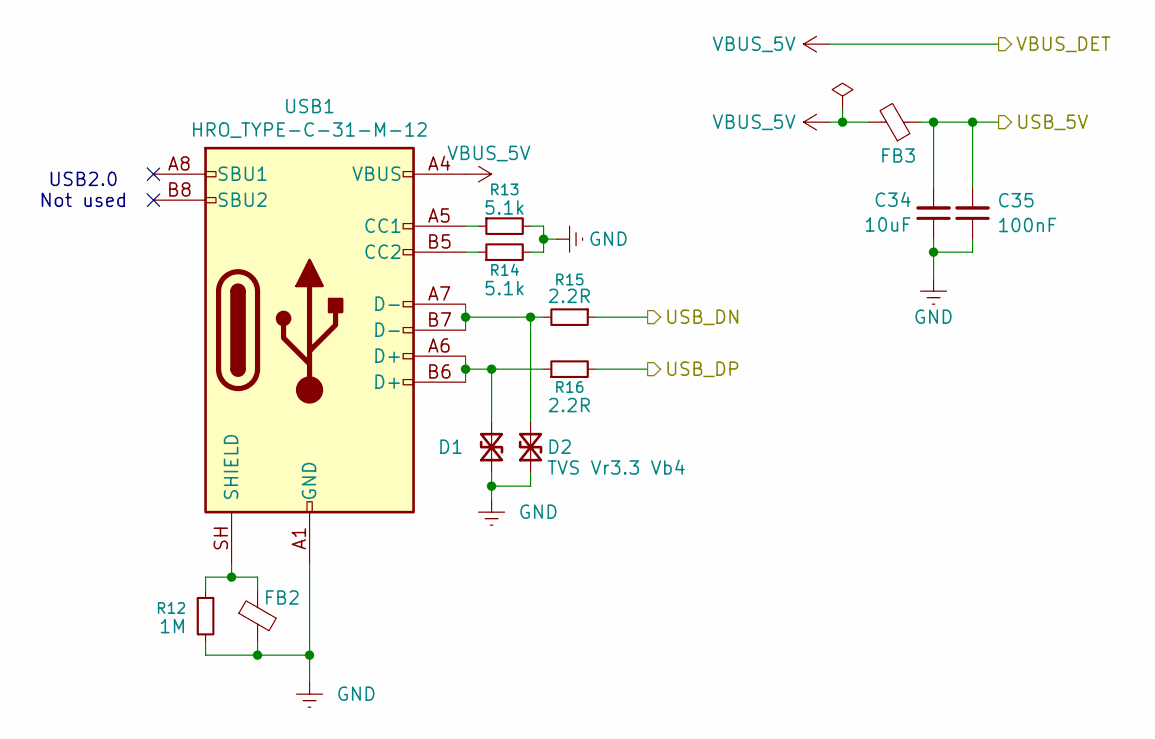
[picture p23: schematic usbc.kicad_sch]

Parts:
C34: 10uF; C_0805_2012Metric; LCSC PART NAME C15850
C35: 100nF; C_0402_1005Metric; LCSC PART NAME C1525
D1, D2: TVS Vr3.3 Vb4; D_SOD-323; LCSC PART NAME C19077496
FB2, FB3: 120R; R_0603_1608Metric; LCSC PART NAME C14709
R12: 1M; R_0402_1005Metric; LCSC PART NAME C26083
R13, R14: 5.1k; R_0402_1005Metric; LCSC PART NAME C25905
R15, R16: 2.2R; R_0402_1005Metric; LCSC PART NAME C25092
USB1: HRO_TYPE-C-31-M-12; USB_C_Receptacle_HRO_TYPE-C-31-M-12; LCSC PART NAME C165948

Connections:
/USB_DN: R15.1; also elsewhere on the board
/USB_DP: R16.2; also elsewhere on the board
GND: C34.1, C35.1, D1.1 (A1), D2.1 (A1), FB2.2, R12.2, R13.2, R14.2, USB1.A1 (GND), USB1.A12 (GND), USB1.B1 (GND), USB1.B12 (GND); also elsewhere on the board
unnamed: D1.2 (A2), R16.1, USB1.A6 (D+), USB1.B6 (D+)
unnamed: D2.2 (A2), R15.2, USB1.A7 (D-), USB1.B7 (D-)
unnamed: R13.1, USB1.A5 (CC1)
unnamed: R14.1, USB1.B5 (CC2)
unnamed: FB2.1, R12.1, USB1.SH (SHIELD)
VBUS_5V: FB3.2, USB1.A4 (VBUS), USB1.A9 (VBUS), USB1.B4 (VBUS), USB1.B9 (VBUS); also elsewhere on the board
VIN_5V: C34.2, C35.2, FB3.1; also elsewhere on the board

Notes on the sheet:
USB2.0 Not used

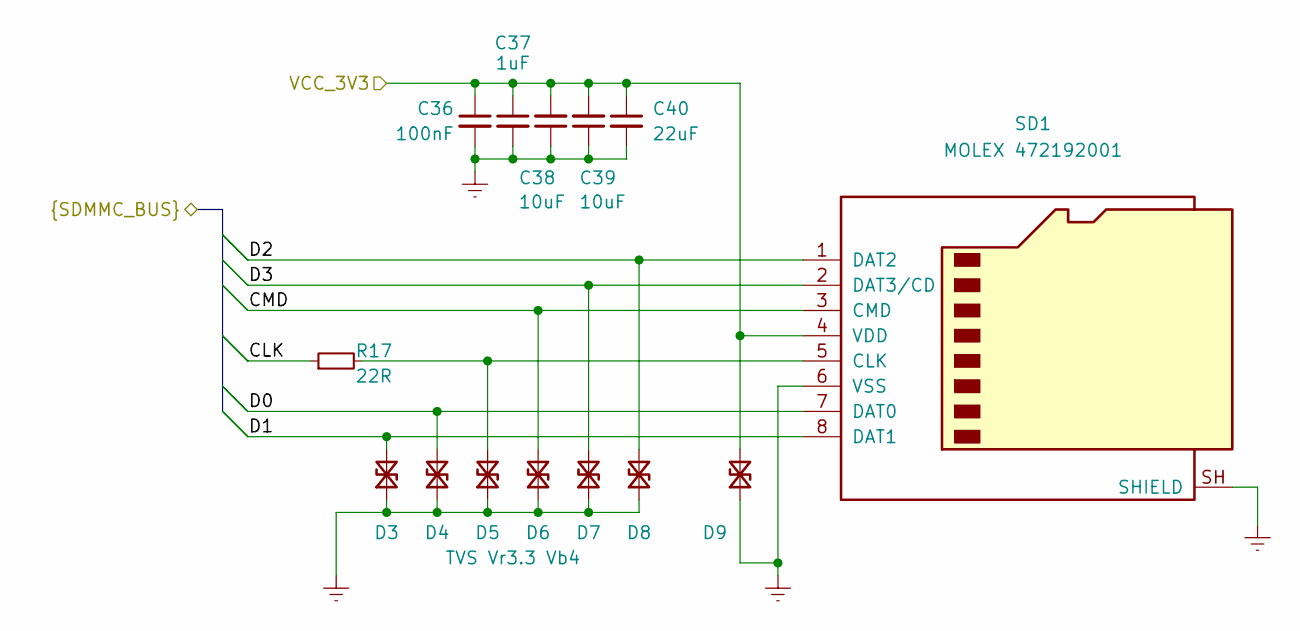
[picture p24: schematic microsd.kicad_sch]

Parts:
C36: 100nF; C_0402_1005Metric; LCSC PART NAME C1525
C37: 1uF; C_0603_1608Metric; LCSC PART NAME C15849
C38, C39: 10uF; C_0805_2012Metric; LCSC PART NAME C15850
C40: 22uF; C_1206_3216Metric; LCSC PART NAME C15850
D3, D4, D5, D6, D7, D8, D9: TVS Vr3.3 Vb4; D_SOD-323; LCSC PART NAME C19077496
R17: 22R; R_0402_1005Metric; LCSC PART NAME C25092
SD1: MOLEX 472192001; microSD_HC_Molex_47219-2001; LCSC PART NAME C164170

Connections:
/MicroSD Port/CLK: R17.1; also elsewhere on the board
/MicroSD Port/CMD: D6.2 (A2), SD1.3 (CMD); also elsewhere on the board
/MicroSD Port/D0: D4.2 (A2), SD1.7 (DAT0); also elsewhere on the board
/MicroSD Port/D1: D3.2 (A2), SD1.8 (DAT1); also elsewhere on the board
/MicroSD Port/D2: D8.2 (A2), SD1.1 (DAT2); also elsewhere on the board
/MicroSD Port/D3: D7.2 (A2), SD1.2 (DAT3/CD); also elsewhere on the board
GND: C36.2, C37.2, C38.1, C39.1, C40.2, D3.1 (A1), D4.1 (A1), D5.1 (A1), D6.1 (A1), D7.1 (A1), D8.1 (A1), D9.1 (A1), SD1.6 (VSS), SD1.SH (SHIELD); also elsewhere on the board
unnamed: D5.2 (A2), R17.2, SD1.5 (CLK)
VCC_3V3_RK: C36.1, C37.1, C38.2, C39.2, C40.1, D9.2 (A2), SD1.4 (VDD); also elsewhere on the board

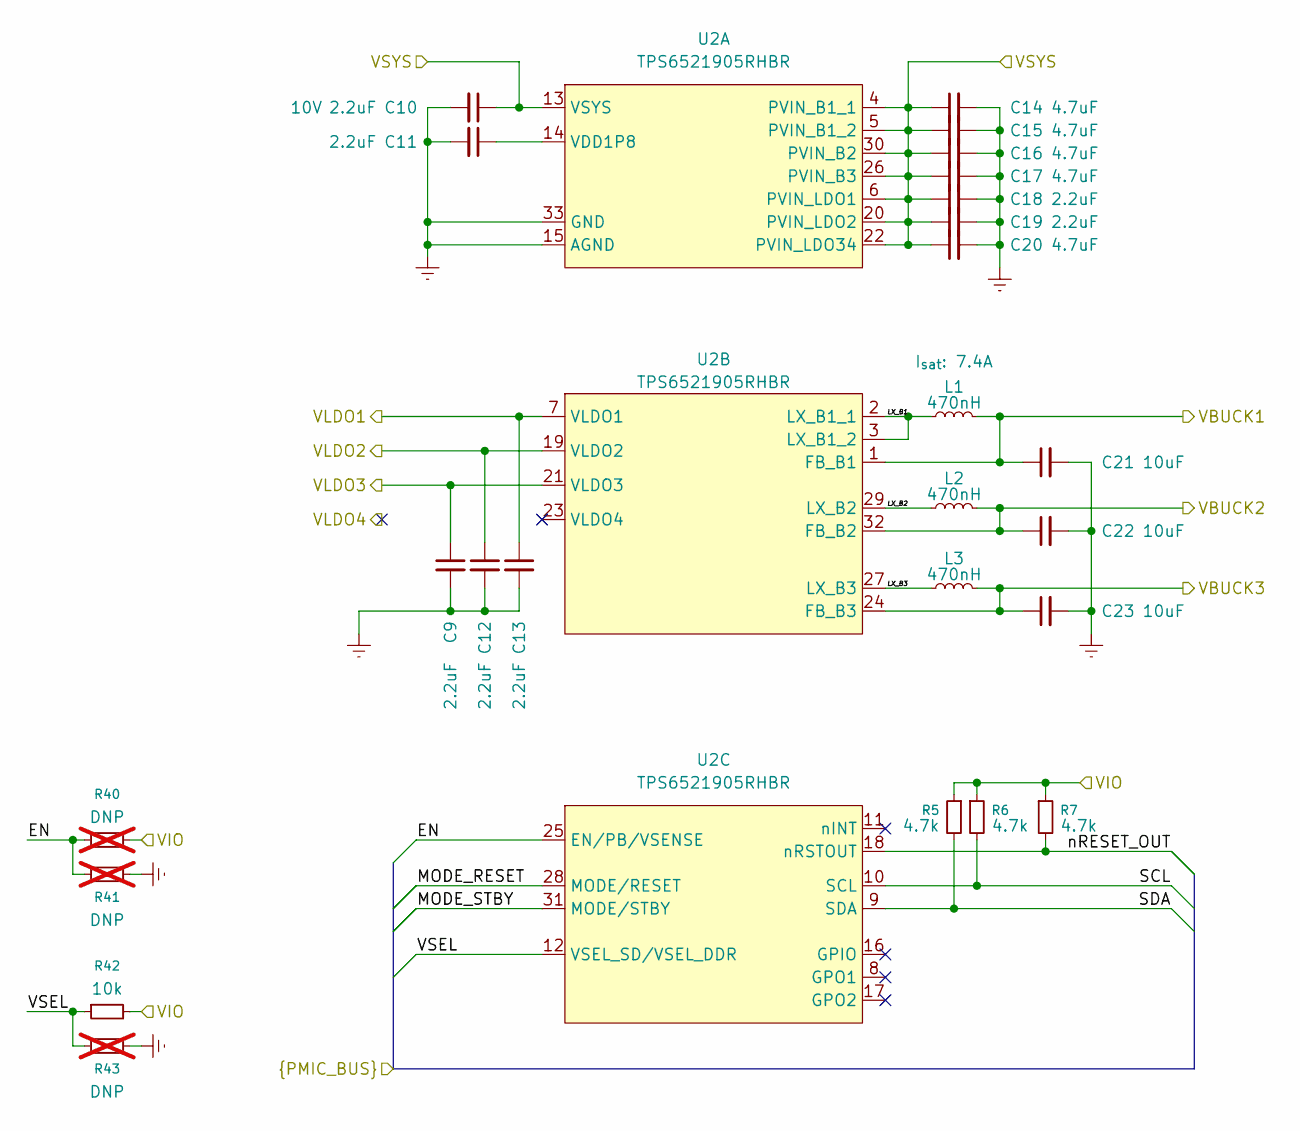
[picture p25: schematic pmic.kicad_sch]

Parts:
C9, C11, C12, C13, C18, C19: 2.2uF; C_0805_2012Metric; LCSC PART NAME C15850
C10: 2.2uF; C_0805_2012Metric; DC Rating 10V; LCSC PART NAME C15850
C14, C15, C16, C17, C20: 4.7uF; C_0805_2012Metric; LCSC PART NAME C15850
C21, C22, C23: 10uF; C_0805_2012Metric; LCSC PART NAME C15850
L1, L2, L3: 470nH; L_0806; LCSC PART NAME C89446
R5, R6, R7: 4.7k; R_0402_1005Metric; LCSC PART NAME C2906860
R40, R41, R43: DNP; R_0402_1005Metric; LCSC PART NAME C2906860; not fitted
R42: 10k; R_0402_1005Metric; LCSC PART NAME C2906860
U2: TPS6521905RHBR; TQFN-32_L5.0-W5.0-P0.50-TL-EP3.7; MPN TPS6521905RHBR; LCSC Part C19379192

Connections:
/EN: R40.1, R41.2, U2.25 (EN/PB/VSENSE); also elsewhere on the board
/MODE_RESET: U2.28 (MODE/RESET); also elsewhere on the board
/MODE_STBY: U2.31 (MODE/STBY); also elsewhere on the board
/SCL: R6.2, U2.10 (SCL); also elsewhere on the board
/SDA: R5.2, U2.9 (SDA); also elsewhere on the board
/TPS65219x/LX_B1: L1.1, U2.2 (LX_B1_1), U2.3 (LX_B1_2)
/TPS65219x/LX_B2: L2.1, U2.29 (LX_B2)
/TPS65219x/LX_B3: L3.1, U2.27 (LX_B3)
/VCC_1V8_RK: C9.1, U2.21 (VLDO3); also elsewhere on the board
/VDD_CPU: C22.1, L2.2, U2.32 (FB_B2); also elsewhere on the board
/VDD_DDR: C23.1, L3.2, U2.24 (FB_B3); also elsewhere on the board
/VDD_SOC: C21.1, L1.2, U2.1 (FB_B1); also elsewhere on the board
/VSEL: R42.1, R43.2, U2.12 (VSEL_SD/VSEL_DDR); also elsewhere on the board
/nRESET_OUT: R7.2, U2.18 (nRSTOUT); also elsewhere on the board
GND: C9.2, C10.2, C11.2, C12.2, C13.2, C14.2, C15.2, C16.2, C17.2, C18.2, C19.2, C20.2, C21.2, C22.2, C23.2, R41.1, R43.1, U2.15 (AGND), U2.33 (GND); also elsewhere on the board
unnamed: C11.1, U2.14 (VDD1P8)
VCC_3V3_CAM: C12.1, U2.19 (VLDO2); also elsewhere on the board
VCC_3V3_RK: C13.1, U2.7 (VLDO1); also elsewhere on the board
VIN_5V: C10.1, C14.1, C15.1, C16.1, C17.1, C18.1, C19.1, C20.1, U2.4 (PVIN_B1_1), U2.5 (PVIN_B1_2), U2.6 (PVIN_LDO1), U2.13 (VSYS), U2.20 (PVIN_LDO2), U2.22 (PVIN_LDO34), U2.26 (PVIN_B3), U2.30 (PVIN_B2); also elsewhere on the board
VSYS_3V3: R5.1, R6.1, R7.1, R40.2, R42.2; also elsewhere on the board

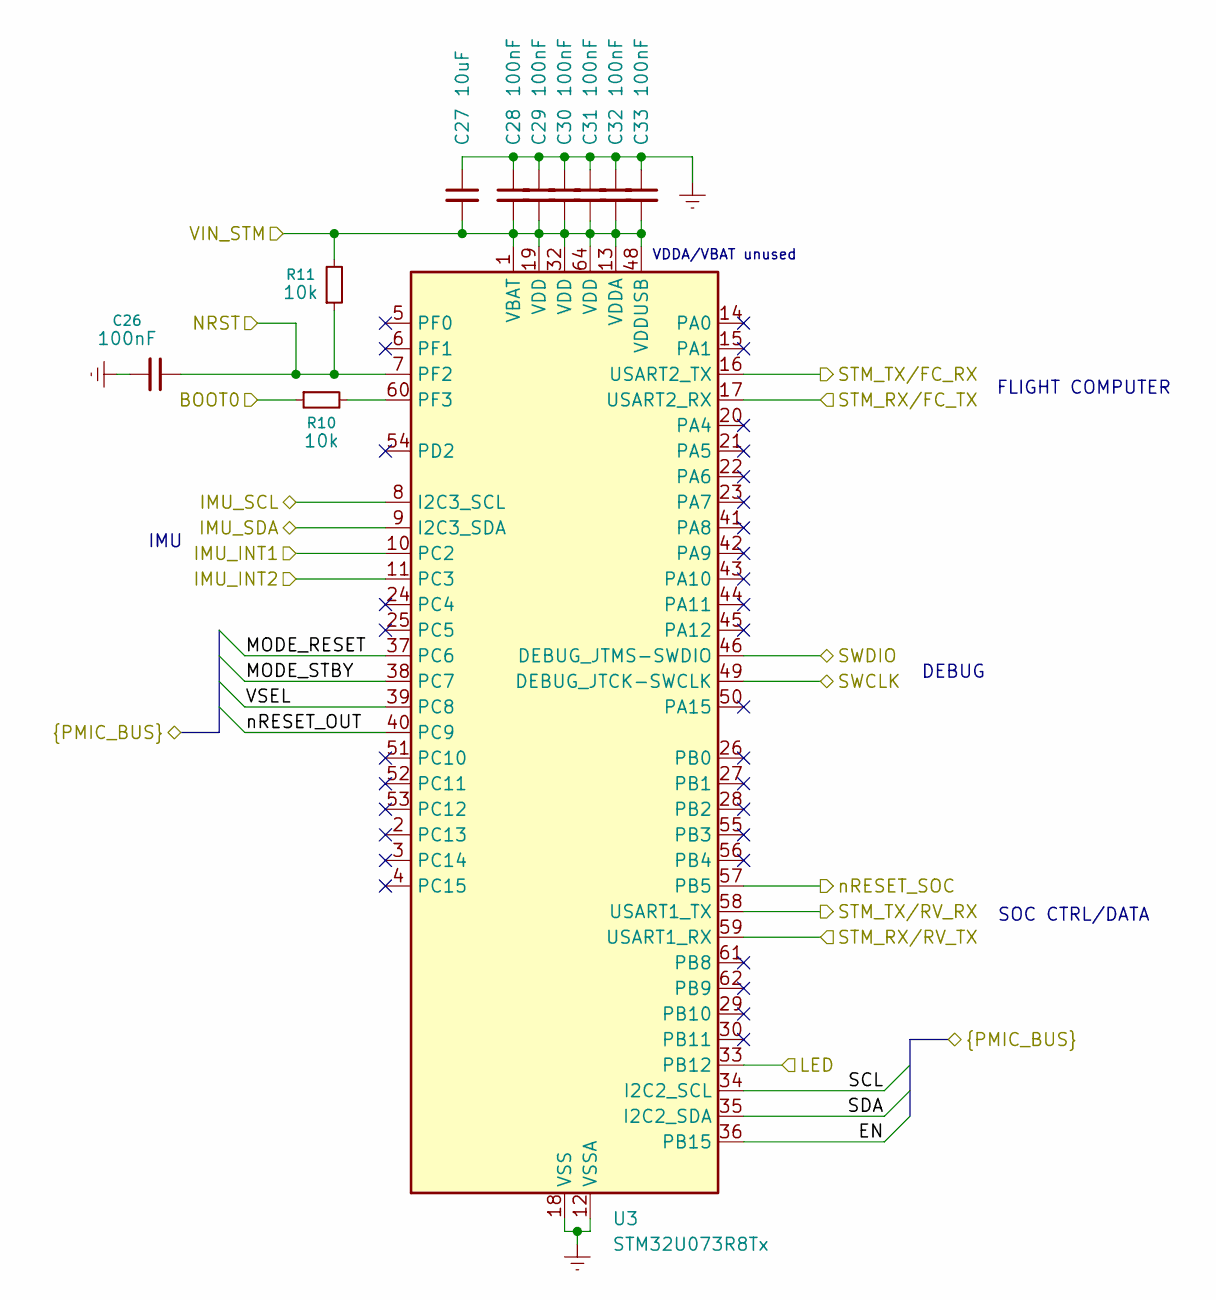
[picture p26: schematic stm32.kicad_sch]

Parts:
C26, C28, C29, C30, C31, C32, C33: 100nF; C_0402_1005Metric; LCSC PART NAME C1525
C27: 10uF; C_0805_2012Metric; LCSC PART NAME C15850
R10: 10k; R_0603_1608Metric; LCSC PART NAME C25744
R11: 10k; R_0603_1608Metric; LCSC PART NAME C112291
U3: STM32U073R8Tx; LQFP-64_10x10mm_P0.5mm

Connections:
/EN: U3.36 (PB15); also elsewhere on the board
/IMU_SCL: U3.8 (I2C3_SCL); also elsewhere on the board
/IMU_SDA: U3.9 (I2C3_SDA); also elsewhere on the board
/LSM6DSMTR/INT1: U3.10 (PC2); also elsewhere on the board
/LSM6DSMTR/INT2: U3.11 (PC3); also elsewhere on the board
/MODE_RESET: U3.37 (PC6); also elsewhere on the board
/MODE_STBY: U3.38 (PC7); also elsewhere on the board
/NRST: C26.1, R11.1, U3.7 (PF2); also elsewhere on the board
/SCL: U3.34 (I2C2_SCL); also elsewhere on the board
/SDA: U3.35 (I2C2_SDA); also elsewhere on the board
/STM32U073x/BOOT0: R10.1; also elsewhere on the board
/STM32U073x/LED: U3.33 (PB12); also elsewhere on the board
/STM32U073x/SWCLK: U3.49 (DEBUG_JTCK-SWCLK); also elsewhere on the board
/STM32U073x/SWDIO: U3.46 (DEBUG_JTMS-SWDIO); also elsewhere on the board
/STM_RX/FC_TX: U3.17 (USART2_RX); also elsewhere on the board
/STM_RX/RV_TX: U3.59 (USART1_RX); also elsewhere on the board
/STM_TX/FC_RX: U3.16 (USART2_TX); also elsewhere on the board
/STM_TX/RV_RX: U3.58 (USART1_TX); also elsewhere on the board
/VSEL: U3.39 (PC8); also elsewhere on the board
/nRESET_OUT: U3.40 (PC9); also elsewhere on the board
/nRESET_SOC: U3.57 (PB5); also elsewhere on the board
GND: C26.2, C27.1, C28.1, C29.1, C30.1, C31.1, C32.1, C33.1, U3.12 (VSSA), U3.18 (VSS), U3.31 (VSS), U3.47 (VSS), U3.63 (VSS); also elsewhere on the board
unnamed: R10.2, U3.60 (PF3)
VSYS_3V3: C27.2, C28.2, C29.2, C30.2, C31.2, C32.2, C33.2, R11.2, U3.1 (VBAT), U3.13 (VDDA), U3.19 (VDD), U3.32 (VDD), U3.48 (VDDUSB), U3.64 (VDD); also elsewhere on the board

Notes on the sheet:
VDDA/VBAT unused
IMU
SOC CTRL/DATA
DEBUG
FLIGHT COMPUTER

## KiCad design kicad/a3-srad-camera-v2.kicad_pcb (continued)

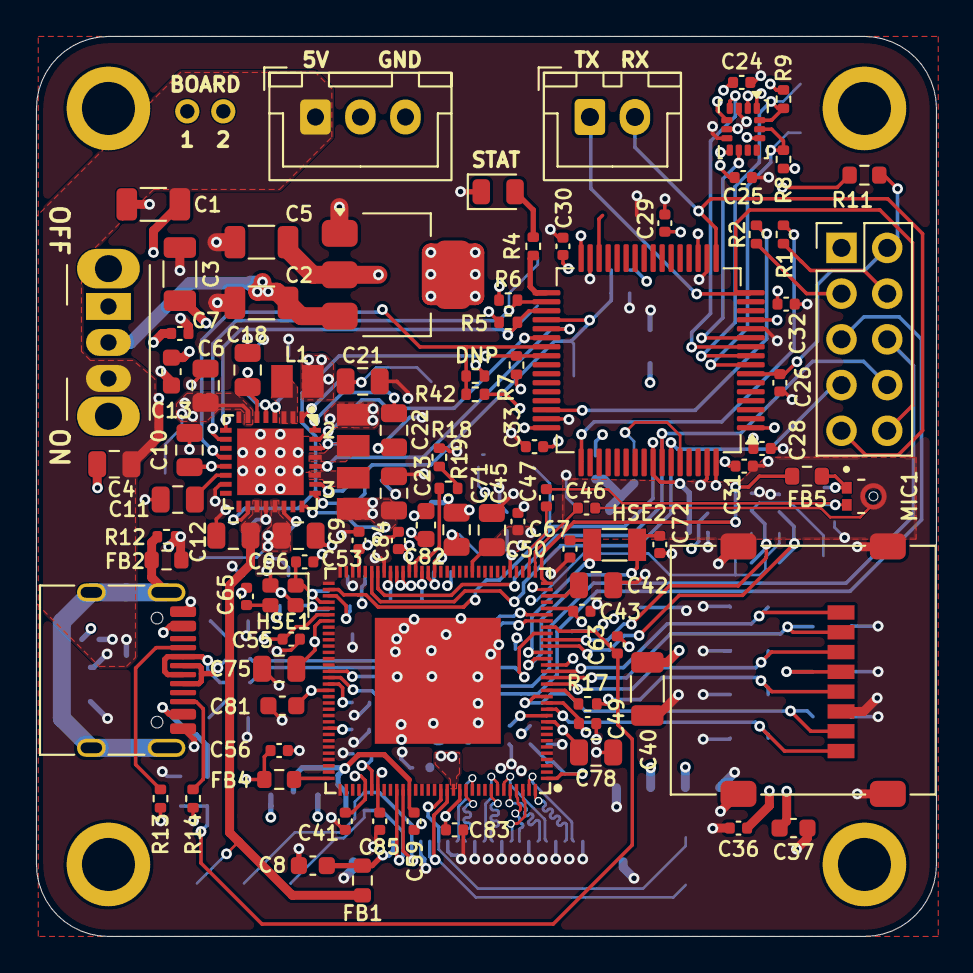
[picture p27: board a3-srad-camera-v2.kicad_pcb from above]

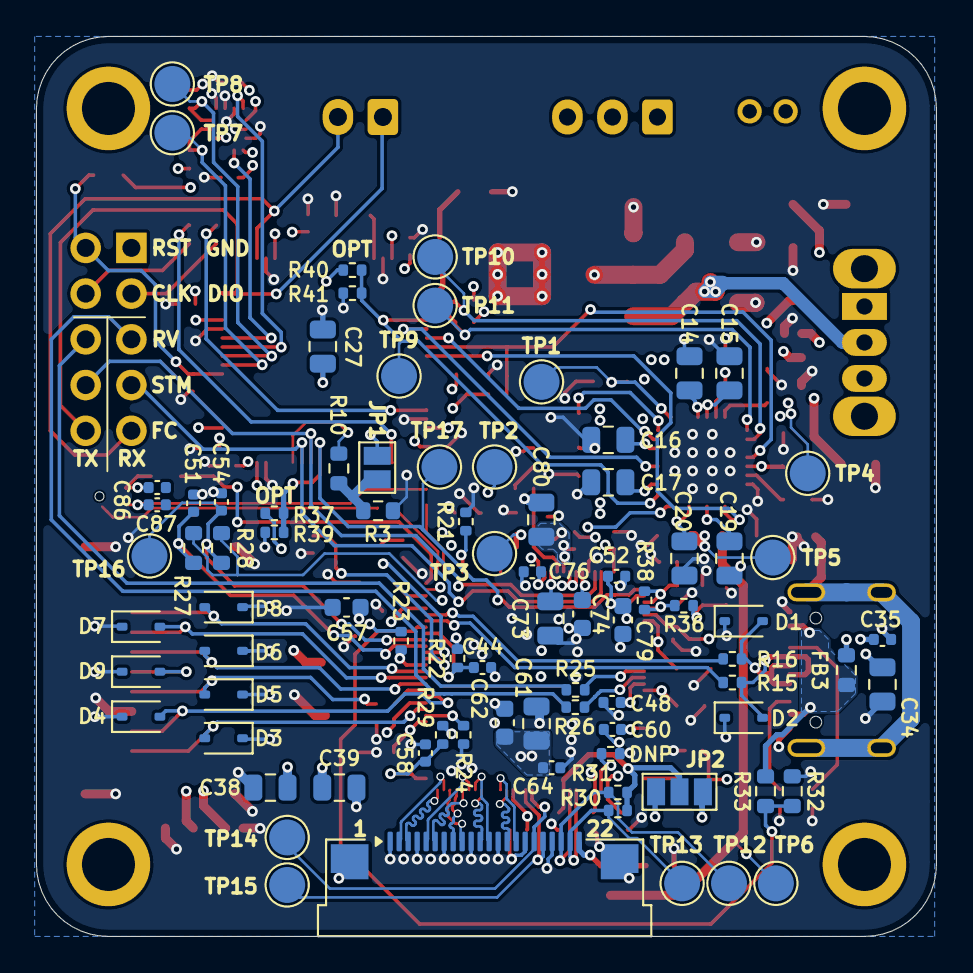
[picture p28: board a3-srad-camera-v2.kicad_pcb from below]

Board: 4 copper layers, 50.0 x 50.0 mm, 181 parts (83 on the bottom side), 97 nets.

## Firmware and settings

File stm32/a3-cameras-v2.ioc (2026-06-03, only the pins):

Mcu.UserName=STM32U073R8Tx
PA2.Signal=USART2_TX
PA3.Signal=USART2_RX
PB12.Signal=GPIO_Output
PB13.Signal=I2C2_SCL
PB14.Signal=I2C2_SDA
PB15.Signal=GPIO_Output
PB5.Signal=GPIO_Output
PB6.Signal=USART1_TX
PB7.Signal=USART1_RX
PC0.Signal=I2C3_SCL
PC1.Signal=I2C3_SDA
PC2.Signal=GPIO_Input
PC3.Signal=GPIO_Input
PC6.Signal=GPIO_Output
PC7.Signal=GPIO_Output
PC8.Signal=GPIO_Output
PC9.Signal=GPIO_Input

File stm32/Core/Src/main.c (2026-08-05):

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
/* Includes ------------------------------------------------------------------*/
#include "app_threadx.h"
#include "main.h"

/* USER CODE BEGIN Includes */
#include "common.h"
#include "pmic.h"

/* USER CODE END Includes */


I2C_HandleTypeDef hi2c2;
I2C_HandleTypeDef hi2c3;

UART_HandleTypeDef huart1;
UART_HandleTypeDef huart2;

/* USER CODE BEGIN PV */

LED_Status_T LED_STATUS = LED_NOMINAL;

/* USER CODE END PV */

void SystemClock_Config(void);
static void MX_GPIO_Init(void);
static void MX_I2C2_Init(void);
static void MX_I2C3_Init(void);
static void MX_USART1_UART_Init(void);
static void MX_USART2_UART_Init(void);
/* USER CODE BEGIN 0 */

/* Wrapper so other modules pmic.c can re-init UART1 to solve residual voltage issue */
void soc_uart_reinit(void)
{
    MX_USART1_UART_Init();
}

/* USER CODE END 0 */

/**
  * @brief  The application entry point.
  * @retval int
  */
int main(void)
{

  /* MCU Configuration--------------------------------------------------------*/

  /* Reset of all peripherals, Initializes the Flash interface and the Systick. */
  HAL_Init();

  /* Configure the system clock */
  SystemClock_Config();

  /* Initialize all configured peripherals */
  MX_GPIO_Init();
  MX_I2C2_Init();
  MX_I2C3_Init();
  MX_USART1_UART_Init();
  MX_USART2_UART_Init();
  MX_ThreadX_Init();

  /* We should never get here as control is now taken by the scheduler */

  /* Infinite loop */
  /* USER CODE BEGIN WHILE */
  while (1)
  {
    /* USER CODE END WHILE */

    /* USER CODE BEGIN 3 */
  }
  /* USER CODE END 3 */
}

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
/**
  * @brief  Period elapsed callback in non blocking mode
  * @note   This function is called  when TIM1 interrupt took place, inside
  * HAL_TIM_IRQHandler(). It makes a direct call to HAL_IncTick() to increment
  * a global variable "uwTick" used as application time base.
  * @param  htim : TIM handle
  * @retval None
  */
void HAL_TIM_PeriodElapsedCallback(TIM_HandleTypeDef *htim)
{
  if (htim->Instance == TIM1)
  {
    HAL_IncTick();
  }
}

/**
  * @brief  This function is executed in case of error occurrence.
  * @retval None
  */
void Error_Handler(void)
{
  /* USER CODE BEGIN Error_Handler_Debug */
  /* User can add his own implementation to report the HAL error return state */
  __disable_irq();
  while (1)
  {
  }
  /* USER CODE END Error_Handler_Debug */
}
#ifdef USE_FULL_ASSERT
/**
  * @brief  Reports the name of the source file and the source line number
  *         where the assert_param error has occurred.
  * @param  file: pointer to the source file name
  * @param  line: assert_param error line source number
  * @retval None
  */
void assert_failed(uint8_t *file, uint32_t line)
{
  /* USER CODE BEGIN 6 */
  /* User can add his own implementation to report the file name and line number,
     ex: printf("Wrong parameters value: file %s on line %d\r\n", file, line) */
  /* USER CODE END 6 */
}
#endif /* USE_FULL_ASSERT */

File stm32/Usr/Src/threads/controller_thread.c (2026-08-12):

#include "controller_thread.h"
#include "pmic.h"

// Power on the SoC on the first loop iteration, without waiting for CMD_START_CAM.
// #define EN_AUTOSTART 1

#define UART_TX_TIMEOUT_MS 100
#define UART_TX_RETRIES 3

#define SOC_START_RETRIES 5
#define SOC_START_BACKOFF_MS 100

// Grace period after power-on for the SoC to boot and send its first heartbeat.
#define SOC_BOOT_TIMEOUT_MS 40000
// Max gap between heartbeats once the SoC is up; must exceed the supervisor's
// heartbeat interval.
#define SOC_HEARTBEAT_TIMEOUT_MS 3000
// Upper bound on a graceful stop: we normally cut power when the SoC reports
// SOC_COMPLETE, but if that never comes (some wedged edge case) we cut it anyway
// rather than wait forever.
#define SOC_STOP_TIMEOUT_MS 20000

static bool soc_powered = false;
static soc_mode_t soc_mode = SOC_MODE_RECORD;
static bool heartbeat_seen = false;
static soc_status_t cached_heartbeat = SOC_STOPPED;
static ULONG last_heartbeat_time = 0;
// Set while a graceful stop is in progress: we have stopped streaming IMU frames
// and are waiting for the SoC to finish saving and report SOC_COMPLETE.
static bool soc_stopping = false;
static ULONG stop_request_time = 0;
// Set once the SoC reports SOC_IDLE: it has parked with /data read-only, so we
// stop streaming IDLE frames and just keep watching the heartbeat until power
// is cut. Reset on each new start/idle command.
static bool soc_idle_acked = false;
// A start/idle command received while the SoC is still powered is deferred: we
// gracefully stop the running session first, then power on in this mode once the
// rails are cut. pending_start gates it; pending_mode is the mode to start in.
static bool pending_start = false;
static soc_mode_t pending_mode = SOC_MODE_RECORD;

static volatile HAL_StatusTypeDef last_soc_tx = HAL_OK;
static volatile HAL_StatusTypeDef last_fc_tx  = HAL_OK;

static status_t current_status(void) {
    if (cached_heartbeat == SOC_ERROR) {
        // The SoC faulted, or a power-on attempt failed (controller_start latches
        // SOC_ERROR here). Report ERROR until the next start/idle command clears
        // it, so the direct and deferred-restart paths surface failures the same
        // way. Checked first so it overrides pending_start/soc_stopping below.
        return REPLY_ERROR;
    }

    if (pending_start) {
        // A restart is in progress: we are gracefully stopping the old session
        // before powering back up. Report STARTING for the whole operation so
        // the FC sees its start request as in-flight rather than a stop.
        return REPLY_STARTING;
    }

    if (!soc_powered) {
        return REPLY_STOPPED;
    }

    if (soc_stopping) {
        // We asked the SoC to stop and are letting it finalize the card. Report
        // STOPPING regardless of the last heartbeat; the heartbeat timeout
        // doesn't apply here (SOC_STOP_TIMEOUT_MS bounds it).
        return REPLY_STOPPING;
    }

    ULONG elapsed = tx_time_get() - last_heartbeat_time;

    if (!heartbeat_seen) {
        // No heartbeat yet: STARTING while booting, ERROR if boot never completes.
        return elapsed > MS_TO_TICKS(SOC_BOOT_TIMEOUT_MS) ? REPLY_ERROR : REPLY_STARTING;
    }

    if (elapsed > MS_TO_TICKS(SOC_HEARTBEAT_TIMEOUT_MS)) {
        return REPLY_ERROR;
    }

    switch (cached_heartbeat) {
        case SOC_RECORDING: return REPLY_RECORDING;
        case SOC_STOPPING:  return REPLY_STOPPING;
        case SOC_STOPPED:   return REPLY_STOPPED;
        case SOC_IDLE:      return REPLY_STOPPED;
        case SOC_ERROR:     return REPLY_ERROR;
        case SOC_INIT:
        default:            return REPLY_STARTING;
    }
}

// Power on the SoC and confirm the PMIC rails came up cleanly, retrying with
// progressive backoff if the interrupt scan reports faults.
static bool soc_start(void) {
    for (int attempt = 0; attempt < SOC_START_RETRIES; attempt++) {
        soc_enable();
        if (!pmic_scan_interrupts()) {
            LED_STATUS = LED_NOMINAL;
            return true;
        }
        LED_STATUS = LED_ERROR;
        soc_disable();
        tx_thread_sleep(MS_TO_TICKS(SOC_START_BACKOFF_MS << attempt));
    }
    return false;
}

// Cut the rails and return to the baseline stopped state.
static void soc_power_off(void) {
    soc_disable();
    soc_powered = false;
    soc_stopping = false;
    heartbeat_seen = false;
    cached_heartbeat = SOC_STOPPED;
}

// Begin a graceful stop of the running session (idempotent). In RECORD mode we
// tag the frames FRAME_CMD_STOP so the SoC saves the partial recording and
// unmounts the card, then reports COMPLETE (where we cut power). Otherwise there
// is nothing to finalize -- IDLE has already parked, and an off/failed SoC has no
// session at all -- so drop straight to the baseline stopped state (which also
// clears any latched start-failure error).
static void soc_begin_stop(void) {
    if (soc_powered && soc_mode == SOC_MODE_RECORD) {
        if (!soc_stopping) {
            soc_stopping = true;
            stop_request_time = tx_time_get();
        }
    } else {
        soc_power_off();
    }
}

// Power on the SoC in the given mode and return the resulting status. On failure
// we latch SOC_ERROR into cached_heartbeat so current_status() reports the
// failure whether the caller uses the return value (direct start) or polls later
// (deferred restart, whose return value is discarded).
static status_t controller_start(soc_mode_t mode) {
    soc_mode = mode;
    heartbeat_seen = false;
    soc_stopping = false;
    soc_idle_acked = false;
    soc_powered = soc_start();
    cached_heartbeat = soc_powered ? SOC_INIT : SOC_ERROR;
    if (soc_powered) {
        last_heartbeat_time = tx_time_get();
    }
    return current_status();
}
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

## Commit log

2026-05-23 Add docs
    [TPS65219 Schematic, Layout Checklist.xlsx]
2026-05-23 Add almost complete PCB v2
    [F32Q-1A7H1-11022.STEP, MOLEX_0472192001.STEP, Micro SD Card.STEP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]
2026-05-24 PCB before switching STM32
    [a3-srad-camera-v2.kicad_pcb, usbc.kicad_sch]
2026-05-24 Switch to lower-cost STM32U0
    [stm32.kicad_sch]
2026-05-24 Init STM32 project for U073C8
2026-05-25 Add missing passives and microphone
    [IM72D128 MEMS microphone.stp, a3-srad-camera-v2.kicad_pcb, a3-srad-camera-v2.kicad_sch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]
2026-05-28 Small changes to PCB, add fab plugin
    [pmic.kicad_sch, rv1106.kicad_sch]
2026-05-28 Correct PMIC 3d model
    [a3-srad-camera-v2.kicad_pcb]
2026-05-28 Footprint + silkscreen corrections
    [500SSP1S1M6QEA.step, a3-srad-camera-v2.kicad_pcb, a3-srad-camera-v2.kicad_sch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]
2026-06-01 Final changes before order
    [CMM-2718AB-3815NC-TR.step, IM72D128 MEMS microphone.stp, a3-srad-camera-v2.kicad_pcb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]
2026-06-01 Solder paste pattern under QFN chips
    [a3-srad-camera-v2.kicad_pcb, bom.csv, designators.csv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]
2026-06-03 Add IMU driver
2026-06-16 Minor kicad changes
    [a3-srad-camera-v2.kicad_pcb, a3-srad-camera-v2.kicad_sch, imu.kicad_sch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]
2026-06-16 Update config for STM32U037
2026-06-16 Get debug output working, switch to variadic print function
2026-06-16 Init threads properly
2026-06-16 Status LED thread, IMU debug work
2026-06-16 Basic PMIC driver, confirm chip works
2026-06-20 Finally get PMIC working and outputting all voltages
    [a3-srad-camera-v2.kicad_pcb, a3-srad-camera-v2.kicad_sch]
2026-07-15 Small tweaks + code for diagnosing PMIC issues, seem to be resolved
    [main.c, pmic.c, pmic.h]
2026-07-24 Convert IMU data to proper ranges
2026-07-24 Clean up uart message formats, simplify controller thread state machine
2026-07-25 Rework controller thread + uart format entirely, now control SoC via PMIC
    [controller_thread.c, main.c, pmic.c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]
2026-08-05 Add driver for controlling camera from flight computer
2026-08-05 LED recording state
2026-08-05 Fix residual voltage issues with PMIC finally
    [main.c, pmic.c, status_led_thread.c]
2026-08-05 Idle mode based on if IMU data is sent or not
2026-08-05 Fix LED status indication
    [controller_thread.c, status_led_thread.c]
2026-08-09 Switch to explicit start/stop/idle commands from STM32
2026-08-12 Prevent new start commands from cutting power if the SoC is already on
    [controller_thread.c]
2026-08-15 Add script tools for interacting with cameras + SD cards
2026-08-15 Add README manual for operating cameras

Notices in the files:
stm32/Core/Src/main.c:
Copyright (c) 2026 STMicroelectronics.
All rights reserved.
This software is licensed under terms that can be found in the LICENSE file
